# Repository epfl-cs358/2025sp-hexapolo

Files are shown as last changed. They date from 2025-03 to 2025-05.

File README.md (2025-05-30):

# 2025sp-hexapolo

## Table of Contents

- [Project Overview](#project-overview)
- [Features & Operation](#features-and-operation)
- [Hardware Requirements](#hardware-requirements)
- [Software Requirements](#software-requirements)
- [Installation](#installation)
- [Project Structure](#project-structure)
- [Acknowledgments](#Acknowledgments)
- [License](#license)

## Project Overview

The Hexapolo Bot is a six-legged robot that can find and follow a person by listening to their
voice and looking at them. It starts by saying “Marco” and waits for someone to reply “Polo.”
When it hears the reply, the robot uses four microphones to figure out which direction the sound
came from. Then, it turns to face that direction and checks with its camera if a person is there.
If it sees someone, it walks toward them and stops when it is about one meter away. After that,
the robot will follow the person as they move.

The project’s goal was to combine sound detection, camera vision, and motor control so the robot
can interact with people.

### Pictures

| Front View | Back View |
| --- | --- |
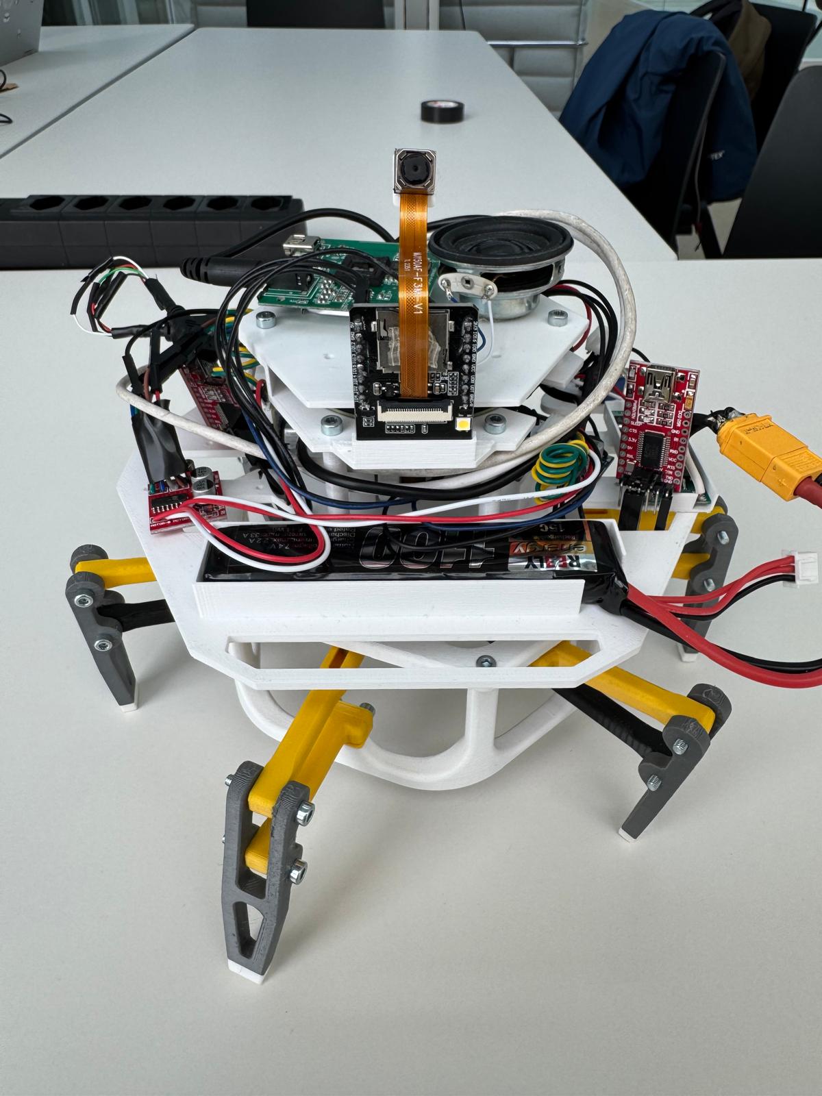
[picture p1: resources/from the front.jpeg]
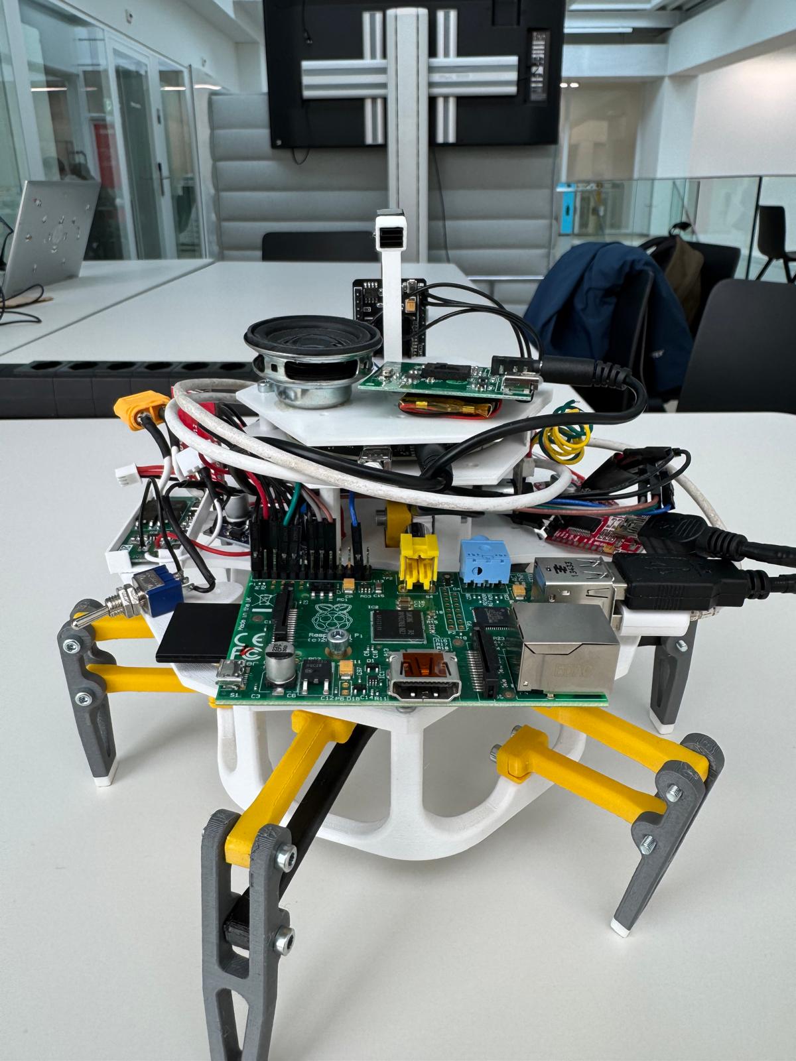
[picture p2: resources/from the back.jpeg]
|  |  |

| Below View | Inside View |
| --- | --- |
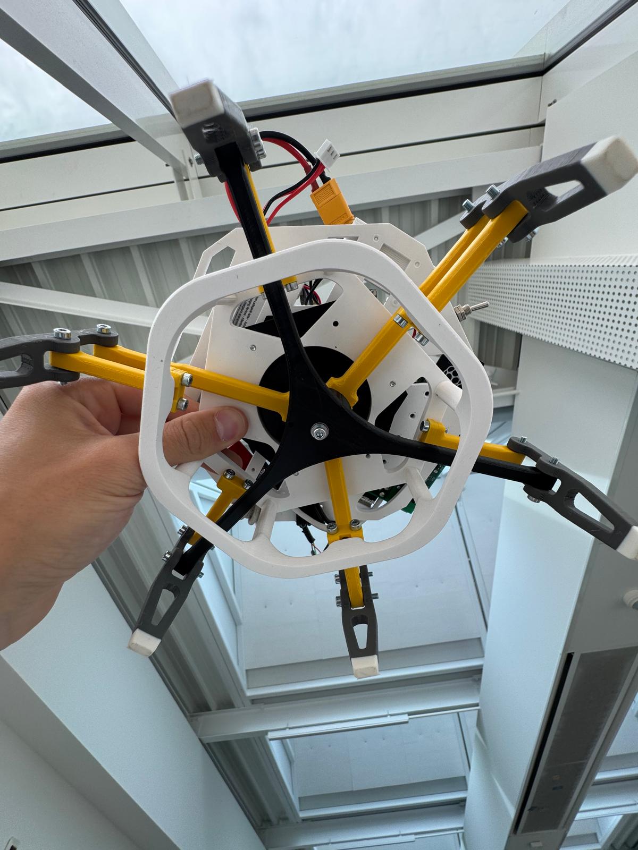
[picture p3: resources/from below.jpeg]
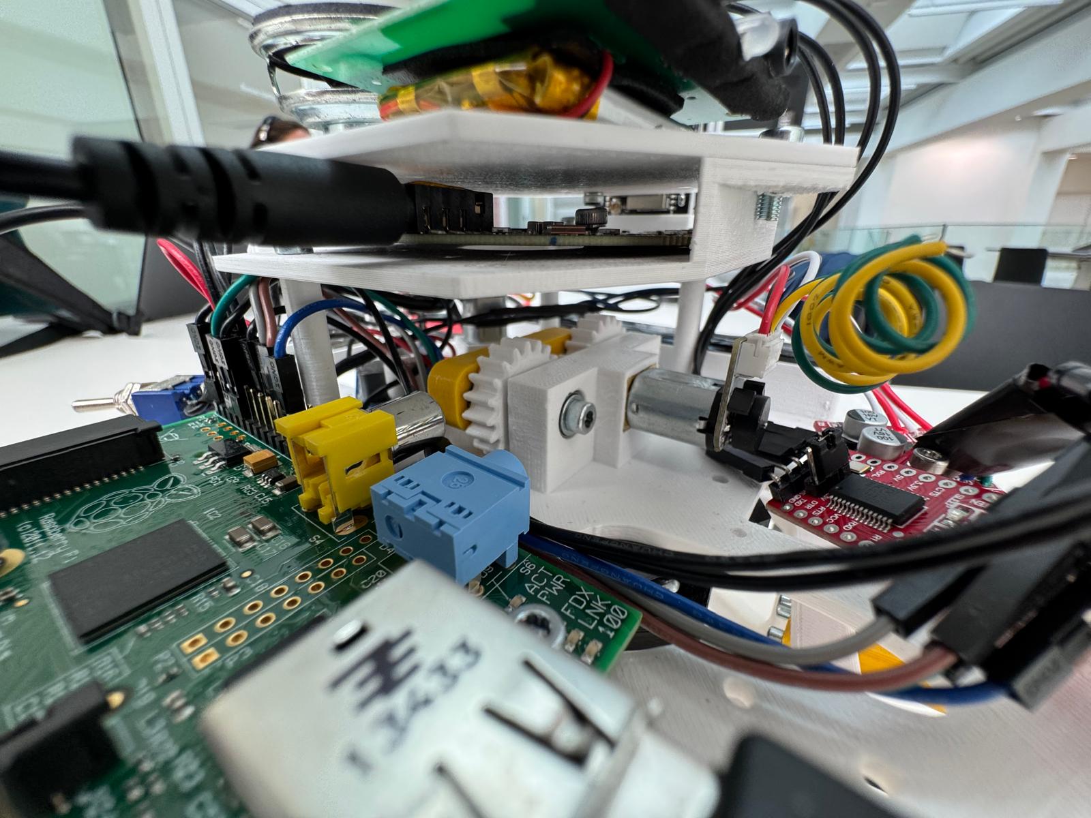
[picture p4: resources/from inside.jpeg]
|  |  |

| Live Video Feed from the Esp32Cam   |
| ----------------------------------- |
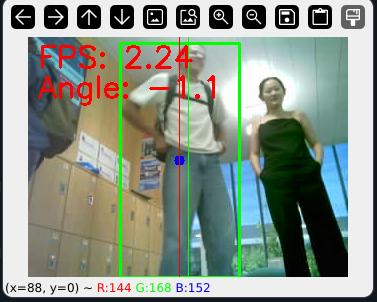
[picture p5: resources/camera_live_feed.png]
|  |

### Videos

Video clip of hexapolo having its first steps :

https://github.com/user-attachments/assets/a82f1c71-6dc9-49f4-babd-78dbcbe76842

Video clip of hexapolo tracking a person :

https://github.com/user-attachments/assets/ddf52e5b-f97f-4ff6-8985-b9ae90d72b5c

### Demo Video

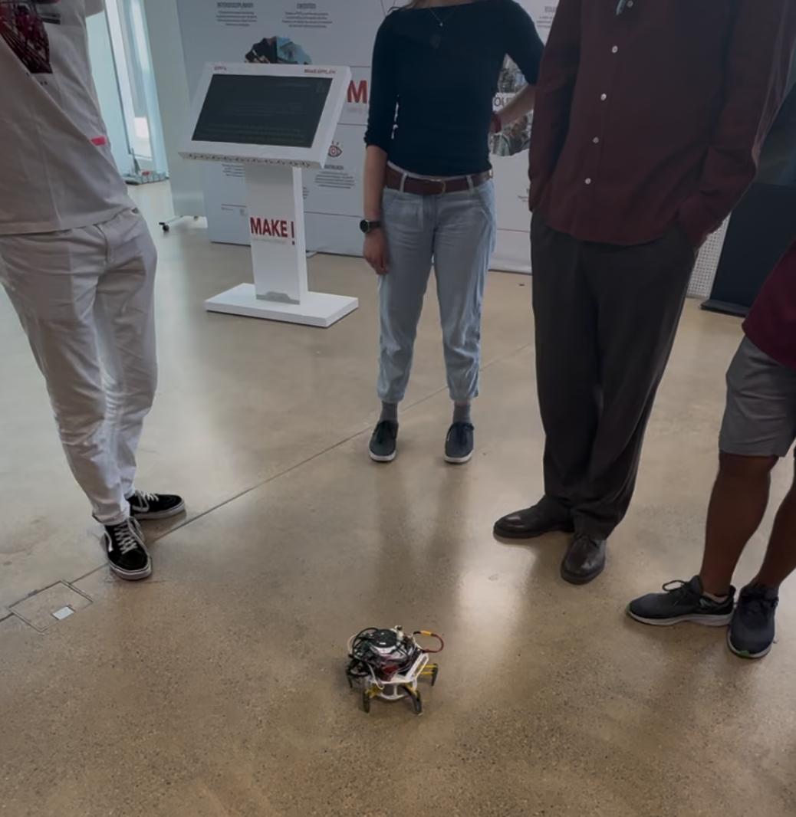
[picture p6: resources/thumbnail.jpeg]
Watch the video (https://youtube.com/shorts/G5ZAEMDvShg)


### Hardware overview

The Legs and mechanical links to control the legs :
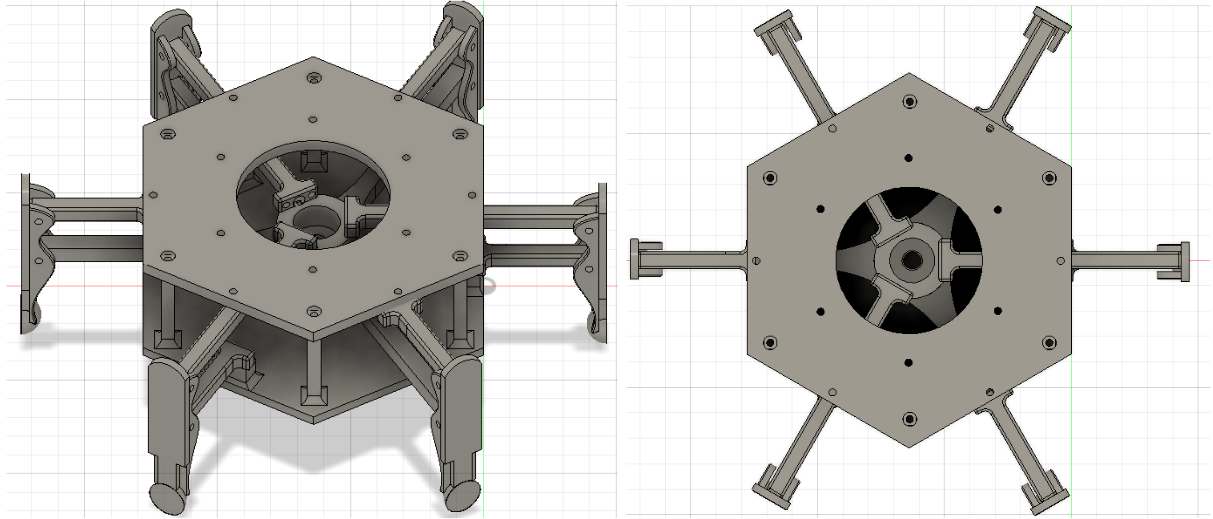
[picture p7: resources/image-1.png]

T-bar, gears and motors to rotate heads and control the movement of the legs :
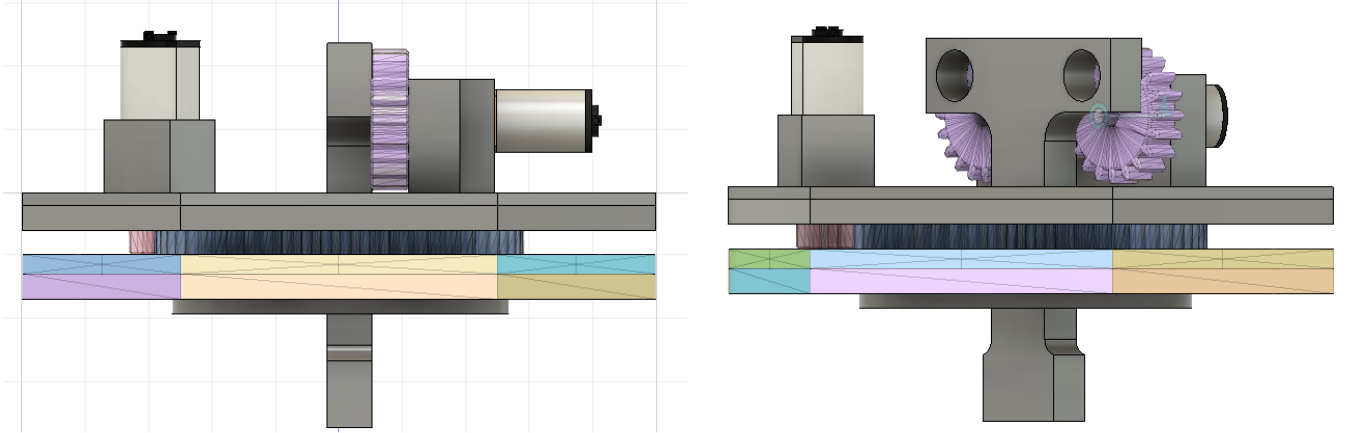
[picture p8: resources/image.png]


### Electrical Overview

Please note that the following diagram does not include the USB connections between the
FTDI board and the Raspberry Pi as well as that between the microphone array (also not
included) and the Raspberry Pi. Furthermore, note that the speaker amplifier will also be wired
to a 3.5mm headphone jack, which will plug into the microphone array, through its A+ and A-
ports.
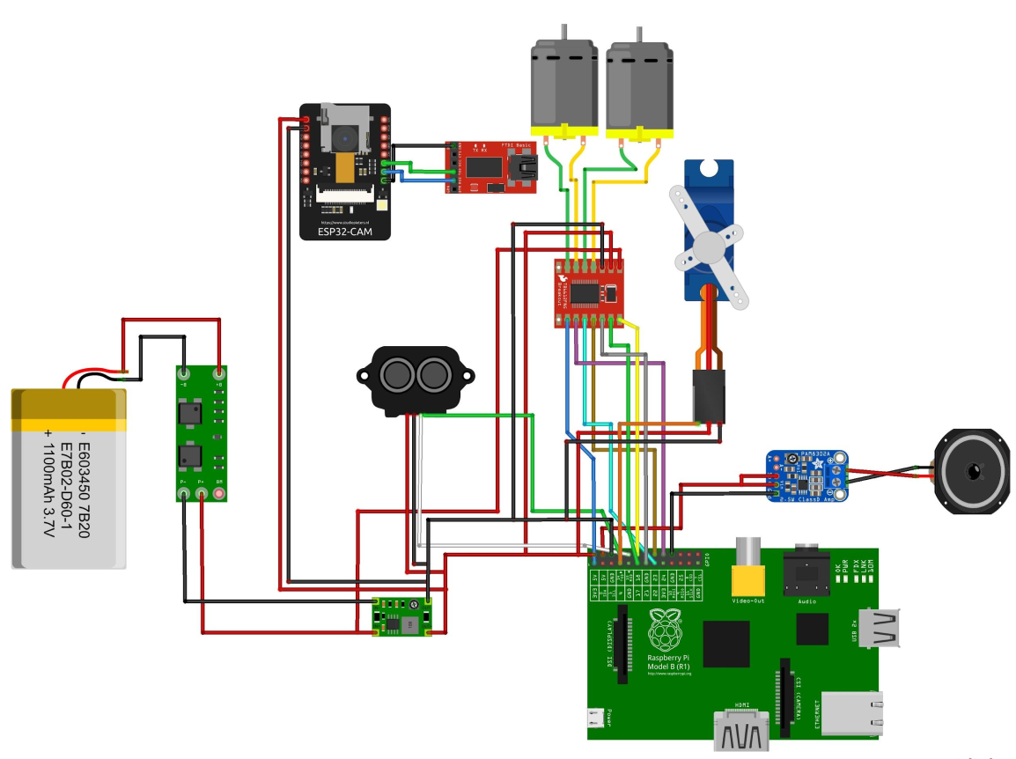
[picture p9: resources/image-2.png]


## Features and Operation

- **Keyword Detection:** The robot will listen for the word “Polo” and react when it hears it.
- **Sound Direction Estimation:** It will use four microphones and a time difference of arrival
  (TDoA) method to figure out which direction the sound came from.
- **Turning Toward the Sound:** After detecting the direction of the sound, the robot will rotate
  to face that direction.
- **Visual Detection:** The robot will use its camera to check if there is a person in front of it.
- **Walking Toward the Person:** The robot will move toward the person and stop when it is
  about 50 cm away.

The following is an overview of the decision tree outlining Hexapolo's main algorithm :



## Hardware Requirements

### Computer

- **Raspberry Pi 1**

  Note : none of our scripts were tested on any Raspberry Pi other than RPi1. However, because of good backward compatibility, all scripts tested on RPi1 should work on any next iteration of the board. Furthermore, you might encounter a few difficulties linked to the limited computing capabilities of the RP1. Using a more recent iteration of the Raspberry Pi, such as the RPi4, will make the reproducibility process significantly easier.

### Power Source

- **2S 7.4V LiPo battery** (e.g. 2S 7.4V lipo 1100mAh 15C with xt60 connector)
- **DC-DC buck converter** (e.g. WaveShare 6-36V to 5V/3.3V 4A DC-DC buck step down converter)

### Sensors

- **Mic Array** (e.g. ReSpeaker Mic Array v2.0)
- **esp32 Camera** (e.g. AI thinker esp 32-cam)
- **FTDI USB-to-serial** (e.g. FTDI FT232RL USB To TTL Serial Adapter Module)

### Sound Output & Speaker

- **Buzzer** (e.g. Purecrea Piezo buzzer active)
- **Speaker**

For our implementation, we stripped out both the speaker and the amplifier from an unbranded speaker. In the same way, you could use whatever speaker with a jack plug you want. Note that the whole build is quite heavy proportionally to the motors, choose your speaker carefully, the lighter the better. We chose this component to save weight, and you might find this approach useful as well.

### Actuators

- **2x 300rpm 6V n20 motor** (200rpm motors would also work)
- **1.2A DC Motor Driver** (e.g. DFRobot Fermion TB6612FNG 2x1.2A DC Motor Driver)
- **Battery Protection Board** (e.g. 8.4V 2S 20A Lithium Battery Protection BMS Protection Board)

### Mechanical Components

- **10x 8x4x3 Ball Bearing**

### Electrical Interfaces

- **Electrical Switch**
- **USB-A to Micro-USB cable**
- **USB-A to Mini-USB cable**

The combined weight of all the cables and wires might be too heavy for the motors to move effectively with the rest of the build. We suggest that you cut them short and solder the wires inside.

## Software Requirements

### OS

- **Linux (Debian)** running on the RPi1

### Dependencies

Due to the multiple features of our project, the use of computer vision and audio processing, a large, yet lightweight, set of dependencies need to be installed. They are all listed in the following file below :

- [Dependencies List](software/requirements.txt)

Among the list of software requirements, you'll find program that are crucial to make this project work. More specifically :

On Linux :

- **Minicom :** serial communication program used to run program in the Raspberry Pi from remote shell. This solution is heavily used and eliminates the need to connect additional peripherals to the RPi1 for control. [Minicom GitLab repository](https://salsa.debian.org/minicom-team/minicom)

On Windows :

- **PuTTY :** SSH and telnet client for Windows plateform. [PuTTY website](https://www.putty.org/)

## Installation

On the RPi1, download the libraries as a .tar.gz file :

```
pip download --no-binary :all: -r requirements.txt
```

Then, copy the downloaded libraries to a usb flash drive and transfer them to the RPi1.

On your laptop :

```
pip install -r requirements.txt
```

## Project Structure

The repository is organized as follows, important files have been highlighted:

    CAD/
    ├── Electrical Components                                     # 3D files for a few electrical components we use
    │   ├── ...
    │   └── ...
    ├── Electronic plate
    ├── Internal Mechanics                                        # 3D files for each mechanical piece of the gearbox
    │   └── ...
    ├── Moving Parts                                              # 3D files for each piece of the body
    │   └── ...
    └── New head with larger base plate                           # 3D files for each piece of the head
        └── ...
    docs/
    software/
    ├── control                                                   # Basic scripts to control hexapolo
    │   └── __pycache__
    ├── esp                                                       # Scripts handling the communication between the laptop and hexapolo
    ├── laptop                                                    # Scripts processing the video feed from the esp32 cam and communicating with it via Wifi
    ├── machine_learning                                          # Scripts used to train the ML model
    └── pi                                                        # Scripts running on the RPi 1
        ├── model
        │   ├── ...
        │   └── ...
        └── usb_4_mic_array                                       # Scripts related to audio processing with the mic array
            ├── single_frequency_sound_recognizance               # Scripts to recognize a single frequency sound in the case where the voice recognition model couldn't work
            └── test                                              # Unit tests

## Acknowledgments

We drew inspiration for Pilotgeek's project ([YouTube video](https://www.youtube.com/watch?v=cc_Njp_cz18)) that demonstrated a similar concept of a six-legged robot. His work provided valuable insights and helped us build Hexapolo.

## License

This project is licensed under the MIT License.

You are free to use, modify, and distribute this software, provided that proper attribution is given to the original authors. For more details, please refer to the LICENSE file included in this repository.

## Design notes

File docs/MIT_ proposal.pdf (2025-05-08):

Making Intelligent Things: HexaPolo Bot

# HexaPolo Bot: Revised Team Project Proposal

Zakaria Laribi, Nagyung Kim, Roméo Maignal, Tuan Dang Nguyen

## 1. Introduction

Robots that can sense and react to their surroundings are becoming more common, and combining different types of sensors can make these robots smarter and more interactive. This project explores how a walking robot can use sound and vision together to find and follow a person. The idea is inspired by the classic game Marco Polo, where one player has to find another by listening to their voice.

Instead of relying only on one sensor, the Hexapolo Bot uses microphones, a camera, and a lidar scanner to understand its environment. This project is a way to experiment with how different technologies—such as sound direction detection and computer vision—can be used to build a robot that moves and reacts to people in real time. The focus is not only on making the robot move but also on making it respond to human interaction in a playful and intelligent way.

## 2. Extended Project Description

### 2.1. Project Overview

The Hexapolo Bot is a six-legged robot that can find and follow a person by listening to their voice and looking at them. It starts by saying “Marco” and waits for someone to reply “Polo.” When it hears the reply, the robot uses four microphones to figure out which direction the sound came from. Then, it turns to face that direction and checks with its camera if a person is there. If it sees someone, it walks toward them and stops when it is about one meter away. After that, the robot will follow the person as they move.

The project’s goal is to combine sound detection, camera vision, and motor control so the robot can interact with people. The robot will also have optional features, like working in a noisy room or avoiding obstacles using a lidar scanner. The work is divided into small steps to make sure each part works well before moving to the next.

### 2.2. Functional Specifications

The Hexapolo Bot will be able to do several things to find and follow a person.

These are the main features it needs to have:

- Keyword Detection: The robot will listen for the word “Polo” and react when it hears it.
- Sound Direction Estimation: It will use four microphones and a time difference of arrival (TDoA) method to figure out which direction the sound came from.
- Turning Toward the Sound: After detecting the direction of the sound, the robot will rotate to face that direction.

- Visual Detection: The robot will use its camera to check if there is a person in front of it.
- Short Verbal Response: Once the robot detects a person, it will say a short phrase to confirm it.
- Walking Toward the Person: The robot will move toward the person and stop when it is about one meter away.
- Following the Person: After reaching the person, the robot will follow them as they move around.

Optional Features:

- Noise Handling: The robot will be able to detect the “Polo” keyword even in a noisy room.
- Obstacle Avoidance: The robot will use a lidar scanner to detect obstacles and avoid them while moving.

Here is a decision tree illustrating the functional specifications :

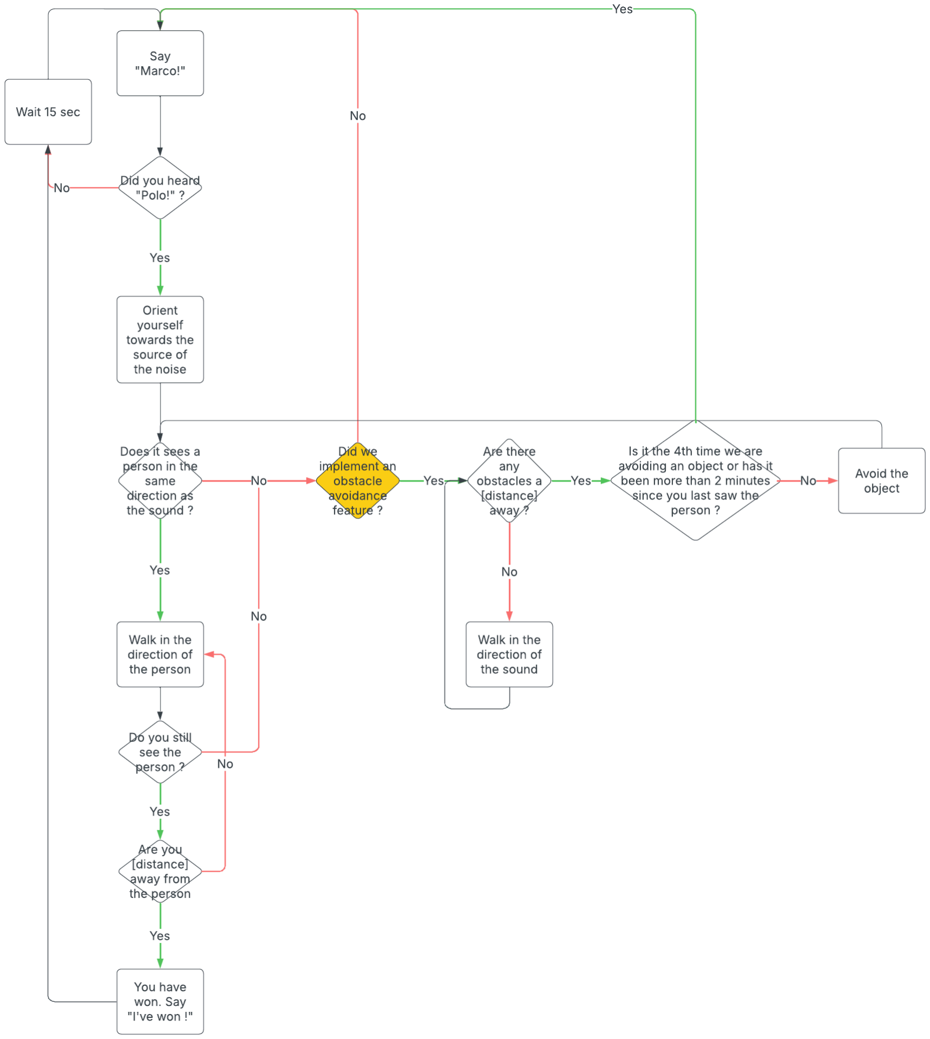
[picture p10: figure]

### 2.3. Technical Approach

The robot’s system uses a combination of microphones, a camera, sensors, and motors, all connected to a Raspberry Pi and ESP32-CAM, as shown in the wiring diagram below.

The robot’s main task is to find and follow a person based on sound and visual information. For this, the following hardware and techniques will be used:

- Sound Direction Detection:
The robot uses a ReSpeaker Mic Array (4-microphone setup) connected to a Raspberry Pi. When someone says “Polo,” the robot compares the tiny time differences of when the sound reaches each microphone. This method is called TDoA (Time Difference of Arrival). It helps the robot calculate which direction the sound is coming from. For sound recognition and direction detection, the project will use the open-source library provided by Seeed Studio: https://github.com/respeaker/mic_array
- Person Detection and Tracking:
The robot uses an ESP32-CAM module with an external antenna to capture video and check if a person is in front. The camera sends the images to the Raspberry Pi for processing. The robot does not need to recognize specific people; it only checks if any person is there.
- Motor and Movement Control:
The robot uses two N20 DC motors to drive its movement and a TB6612FNG motor driver to control the motors safely. It also uses a SG90 servo motor to adjust the camera or other parts if needed.
- Distance-Based Following with TFMini LiDAR
To maintain a consistent following distance of about 1 meter, the robot uses a TFMini LiDAR sensor. It helps the robot follow the person smoothly by constantly checking how far ahead the person is. (This is considering the setup that there are no multiple people close to each other)
- Sound Feedback:
The robot responds with a short phrase using an Adafruit Mini Metal Speaker and a small PAM8302 audio amplifier to make sure the sound is loud enough.
- Power Supply:
The robot is powered by a 2S 7.4V LiPo battery and uses a DC-DC buck converter to safely supply power to the components.

### 2.4. Milestones

To build the Hexapolo Bot step by step, the work is divided into smaller goals, called milestones. Each milestone focuses on one part of the robot’s behavior.

Milestone 1 – Sound Detection & Turning
In a quiet room without obstacles, the robot listens for the word “Polo.” It uses the microphone array and a keyword detection system to recognize the word. Then, it uses the TDoA method to find the direction of the sound. After that, the robot turns toward the sound and uses its camera to look for a person.

Milestone 2 – Walking to the Person
Once the robot detects a person, it moves toward them using its motors. It stops when it is about one meter away. Distance is checked using either the ultrasonic sensor or LiDAR.

Milestone 3 – Following the Person
The robot keeps following the person as they move around. It uses the lidar to keep track of the person’s location and updates its movement.

Milestone 4 (Optional) – Working in Noisy Rooms
The robot will be tested in a noisy environment. It will use sound-processing libraries from the ReSpeaker project to help it detect the “Polo” keyword even when there is background noise.

Milestone 5 (Optional) – Obstacle Avoidance
The robot will use a TFmini Plus LiDAR scanner to detect obstacles while moving. If something is in its path, it will stop and change direction to avoid collisions.

## 3. Complete Technical Drawings

### 3.1. CAD Drawings

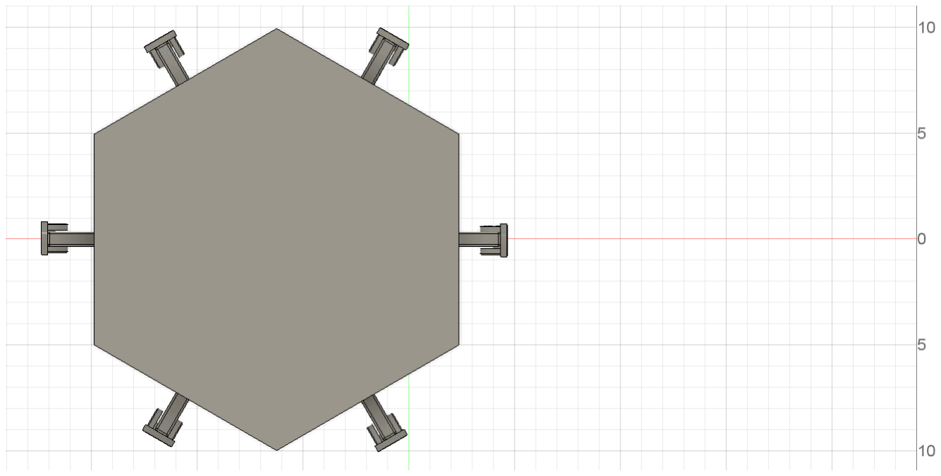
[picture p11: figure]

Figure 1: The prototype looking from above (the numbers on the vertical axis are in cm)

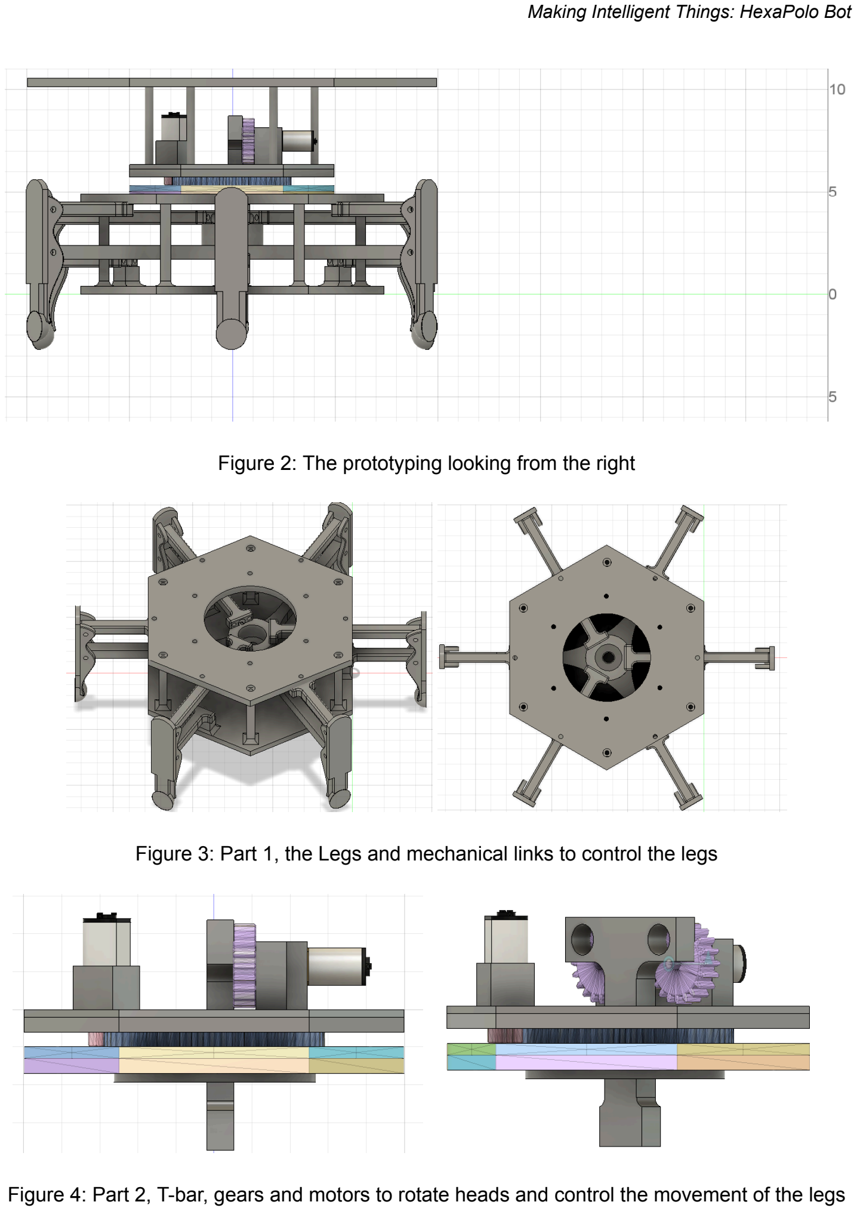
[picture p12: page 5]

Figure 2: The prototyping looking from the right

Figure 3: Part 1, the Legs and mechanical links to control the legs

Figure 4: Part 2, T-bar, gears and motors to rotate heads and control the movement of the legs

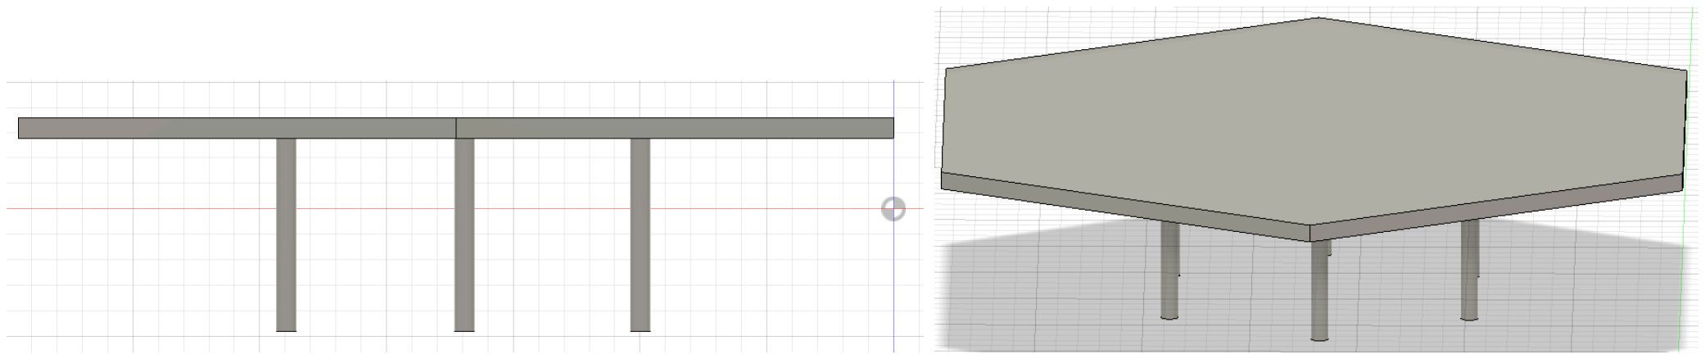
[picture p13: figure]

Figure 5: Part 3, the platform that holds all the electronics

### 3.2. Electrical or Circuit Schematics

Please note that the following diagram does not include the USB connections between the FTDI board and the Raspberry Pi as well as that between the microphone array (also not included) and the Raspberry Pi. Furthermore, note that the speaker amplifier will also be wired to a 3.5mm headphone jack, which will plug into the microphone array, through its A+ and Aports.

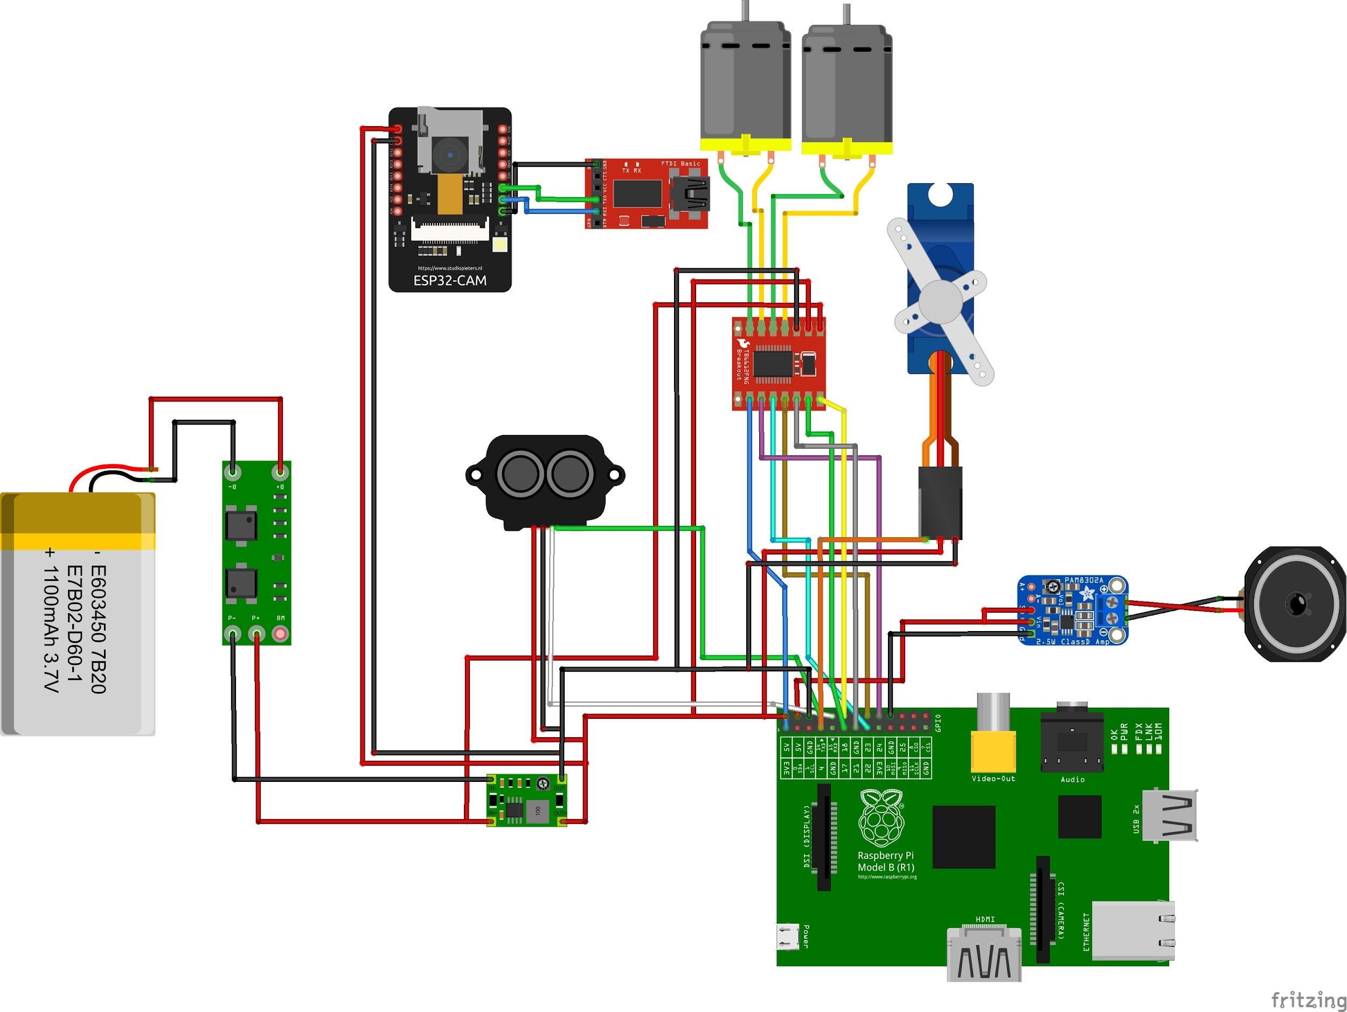
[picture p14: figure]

## 4. Bill of Materials (BOM)

- AI thinker esp32-cam with antenna - 13. - cs358 stock
- FTDI USB-to-serial - 2. - cs358 stock
- sg90 micro servo - 3. - cs358 stock
- raspberry pi 1 B - in stock
- Adafruit Mini Metal Speaker - 8.9 -https://www.digitec.ch/en/s1/product/adafruit-mini-metal-speaker-loudspeaker-electronic s-modules-5998730 (https://www.digitec.ch/en/s1/product/adafruit-mini-metal-speaker-loudspeaker-electronics-modules-5998730)

- DFRobot Fermion TB6612FNG 2x1.2A DC Motor Driver - 14.9 -https://www.digitec.ch/en/s1/product/dfrobot-fermion-tb6612fng-2x12a-dc-motor-driver-d evelopment-boards-kits-24935800 (https://www.digitec.ch/en/s1/product/dfrobot-fermion-tb6612fng-2x12a-dc-motor-driver-development-boards-kits-24935800)
- Tfmini Plus Lidar - 89 -https://www.fruugoschweiz.com/tfmini-plus-lidar-reichweitensensormodul-12-m-reichweite-hohe-bildrate-kleiner-blindbereich-hohe-genauigkeit/p-213832614-455740347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 (https://www.fruugoschweiz.com/tfmini-plus-lidar-reichweitensensormodul-12-m-reichweite-hohe-bildrate-kleiner-blindbereich-hohe-genauigkeit/p-213832614-4557403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)
- 300rpm 6V n20 motor - in stock
- 200rpm 6V n20 motor - in stock
- 2S 7.4V lipo 1100mAh 15C (with xt60 connector) - 12.95 -https://www.conrad.ch/fr/p/reely-pack-de-batterie-lipo-7-4-v-1100-mah-nombre-de-cellul es-2-15-c-softcase-xt60-2582340.html (https://www.conrad.ch/fr/p/reely-pack-de-batterie-lipo-7-4-v-1100-mah-nombre-de-cellules-2-15-c-softcase-xt60-2582340.html)
- WaveShare 6-36V to 5V/3.3V 4A DC-DC buck step down converter - 10.9 -https://www.digitec.ch/en/s1/product/waveshare-6-36v-to-5v33v-4a-dc-dc-buck-step-do wn-converter-development-boards-kits-53542221 (https://www.digitec.ch/en/s1/product/waveshare-6-36v-to-5v33v-4a-dc-dc-buck-step-down-converter-development-boards-kits-53542221)
- OV5640 camera - 9.95 -
https://www.fruugoschweiz.com/ov5640-module-de-camera-pour-carte-logicielle-esp32-cam-5-millions-de-pixels-c/p-331210929-730594189 (https://www.fruugoschweiz.com/ov5640-module-de-camera-pour-carte-logicielle-esp32-cam-5-millions-de-pixels-c/p-331210929-730594189)
- Goobay Jack plug 3.5 mm mono - 2.7 -https://www.digitec.ch/en/s1/product/goobay-jack-plug-35-mm-mono-audio-connectors-20604603 (https://www.digitec.ch/en/s1/product/goobay-jack-plug-35-mm-mono-audio-connectors-20604603)
- Purecrea Piezo buzzer active - 5.9 -https://www.digitec.ch/en/s1/product/purecrea-piezo-buzzer-active-development-boardskits-38633745 (https://www.digitec.ch/en/s1/product/purecrea-piezo-buzzer-active-development-boards-kits-38633745)
- ReSpeaker Mic Array v2.0 - 58.51 -https://www.reichelt.com/ch/en/shop/product/respeaker_mic_array_v2_0-248721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 (https://www.reichelt.com/ch/en/shop/product/respeaker_mic_array_v2_0-248721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)
- PAM8302 2.5W single channel Class D Audio power amplifier - 7.95 -https://www.fruugoschweiz.com/pam8302a-cjmcu-832-pam8302-25-w-einkanal-class-daudio-leistungsverstarkermodul-entwicklungsplatine/p-263124514-578035388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 (https://www.fruugoschweiz.com/pam8302a-cjmcu-832-pam8302-25-w-einkanal-class-d-audio-leistungsverstarkermodul-entwicklungsplatine/p-263124514-578035388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)

Total cost: 239.66

## 5. Work Breakdown Structure

### 5.1. Task Breakdown

The chart below outlines our planned task breakdown for the project. While it gives a clear structure for how we aim to progress week by week, we are approaching the plan with flexibility and will adapt it as needed based on testing outcomes and unexpected challenges.

The tasks marked as optional represent features we would like to implement if time allows, but they will only be pursued after all core features are completed and working reliably.

The timeline for the core features is intentionally planned with more buffer time to handle possible errors and unexpected issues, while the optional features are scheduled more tightly so that, if we finish the core tasks earlier than expected, we can immediately move forward without losing time.

Week | Task | Dependencies / Note

Week 7: Assemble 3D-printed body, set up camera, motor, and Raspberry Pi environment

7.1 | Print and assemble 3D printed robot body | Independent
7.2 | Set up ESP32-CAM and FTDI programmer, test video stream | In-stock components
7.3 | Research and implement basic person detection (presence only) using ESP32-CAM | In-stock components
7.4 | Set up Raspberry Pi environment (GPIO, Python, libraries) | In-stock components

Week 8: Assemble full electronics, integrate mic array, build first moving robot

8.1 | Receive, test and integrate mic array hardware | Needs delivery
8.2 | Assemble motor driver and one N20 motor, test basic forward/backward movement | Need delivery
8.3 | Test and finalize keyword detection (“Polo”) using mic array
8.4 | Assemble electronics: connect motors, sensors, power system | Needs motor driver, battery
8.5 | Assemble the initial robot | This is the very first moving robot we will have

Week 9 (Milestone 1): Implement sound direction detection & turning behavior for person detection

9.1 | Implement TDoA sound direction detection | Needs working mic array
9.2 | Integrate sound direction detection with motor turning behavior | Needs sound direction + motor setup
9.3 | Integrate person detection with turning behavior | Needs vision + turning working
9.4 | Test: turn + detect in quiet room | First prototype (Milestone 1)

Week 10 (Milestone 2): Add walking-to-person behavior and test approach in quiet room

10.1 | Fix bugs or unstable behavior after prototype test | System improvement
10.2 | Implement walking-to-person behavior and stop at 1m distance | Needs motor + person detection
10.3 | Test: turn + detect + walk-to-person behavior in quiet | Second prototype

room | (Milestone 2)

Week 11 (Milestone 3, full prototype): Implement following the human behavior and complete core Hexapolo Bot features

11.1 | Connect TFmini lidar module to Raspberry Pi
11.2 | Integrate lidar distance data into Raspberry Pi control loop
11.3 | Implement the following person behavior (continuous person tracking) | Builds on turn-detect-walk behavior
11.4 | Test: turn + detect + walk-to-person behavior + follow the person in quiet room | The full Hexapolo bot prototype with all of the essential features (Milestone 3)

Week 12 (Milestone 4): (Optional) Add noise filtering feature and connect lidar module for obstacle avoidance while approaching visible person

12.1 | [Optional] Integrate selected noise filtering method into existing keyword detection pipeline | Needs working keyword detection
12.2 | [Optional] Test: keyword detection performance in simulated noisy environment | Test until which level of noise it can handle, and document it (Milestone 4)
12.3 | [Optional] Design basic obstacle avoidance behavior with lidar (stop & turn when obstacle detected)
12.4 | [Optional] Implement obstacle avoidance while walking toward visible person
12.5 | [Optional] Test: obstacle avoidance in clean room while approaching visible person

Week 13 (Milestone 5): (Optional) Implement search behavior when person is not visible

13.1 | [Optional] Research and choose a method for searching the person when not visible (strategy decision in addition to what we already have, ex. Saying Marco again after 4 trial)
13.2 | [Optional] Integrate search behavior with obstacle avoidance | Requires both search logic + avoidance working
13.3 | [Optional] Test full system: obstacle avoidance + search behavior | Final integrated test (Milestone 5)

### 5.2. Gantt Chart

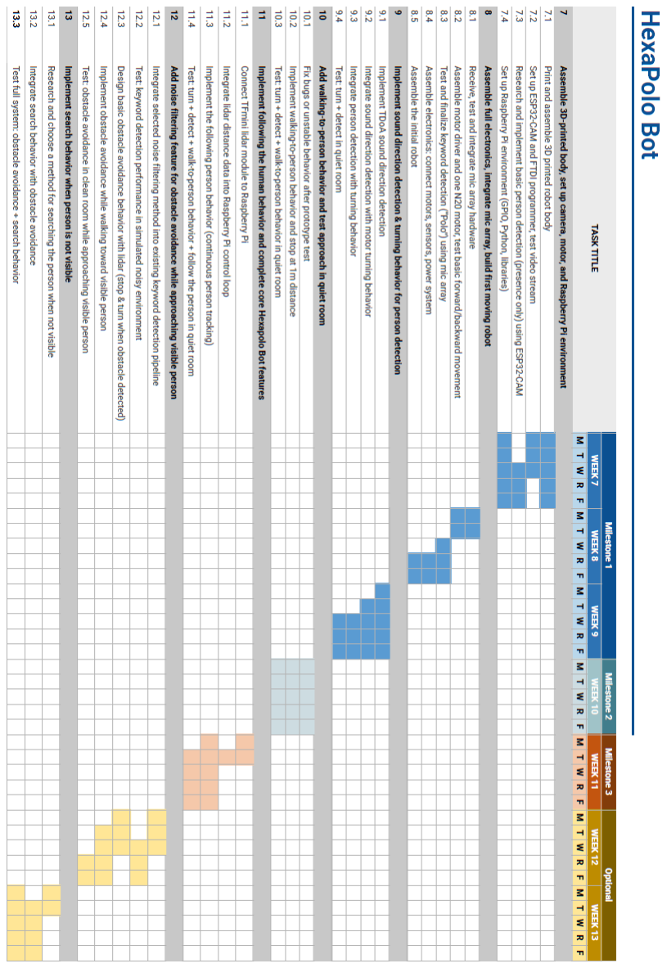
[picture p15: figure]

https://docs.google.com/spreadsheets/d/1xnIqV8nKbMYVABpta7GscwPPvCl3ueHyudp6yGAwllQ/edit?usp=sharing

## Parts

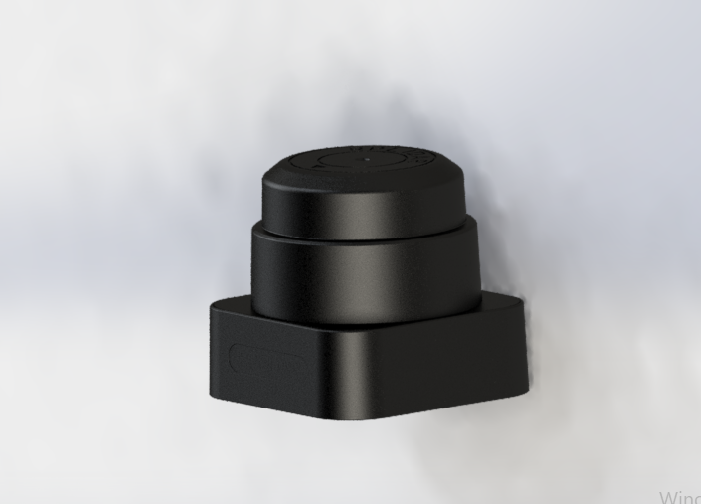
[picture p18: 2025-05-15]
CAD/Electrical Components/rplidar-s1-360-laser-scanner-1.snapshot.2/Ekran görüntüsü 2022-02-06 154033.png

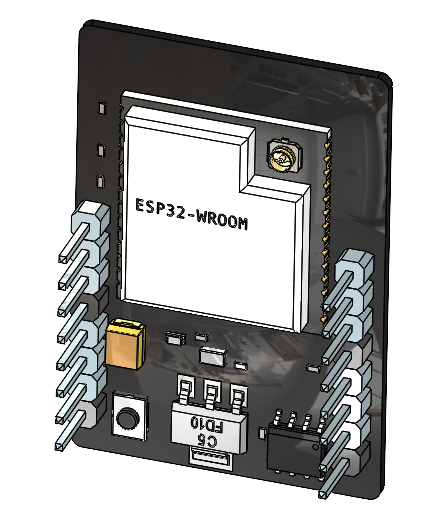
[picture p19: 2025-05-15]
CAD/Electrical Components/esp32-cam-wifi-bluetooth-1.snapshot.5/ESP32 CAM 3.PNG

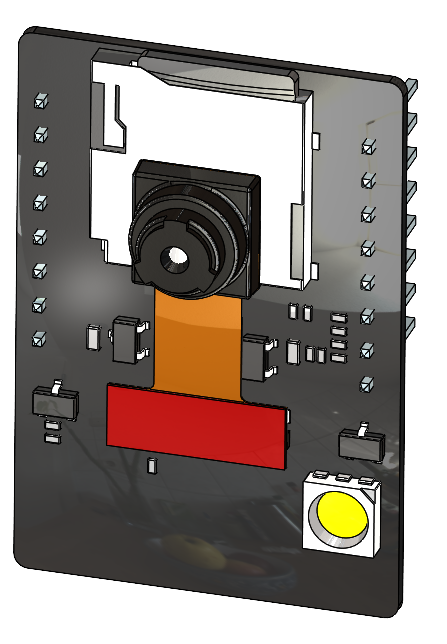
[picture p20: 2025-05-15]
CAD/Electrical Components/esp32-cam-wifi-bluetooth-1.snapshot.5/ESP32 CAM.PNG

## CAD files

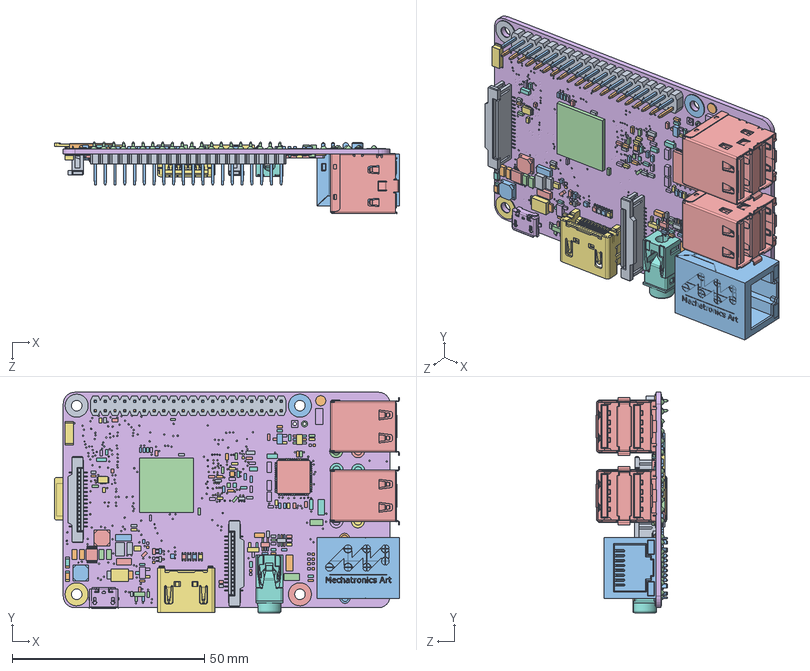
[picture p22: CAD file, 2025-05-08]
CAD/Electrical Components/Solidworks Complete Assembly/Raspberry Pi 3.SLDASM
89.6 x 57.3 x 18.6 mm
Raspberry Pi 3157
Raspberry Pi 3242 x 20
Raspberry Pi 3266 x 20
raspberry_pi_3(bar_180_2x20)
MOLEX_672983090 x 2
molex_0473460001
molex_0471510001
PJ-322
te_1-1734248-5 x 2
MOLEX_1040310811
raspberry_pi_B_(RJ45)
Raspberry Pi 312
Raspberry Pi 314
Raspberry Pi 3172
Raspberry Pi 3173
Raspberry Pi 3174
Raspberry Pi 3175
Raspberry Pi 3176
Raspberry Pi 3177
Raspberry Pi 3178
Raspberry Pi 3179
Raspberry Pi 3180
Raspberry Pi 3181
Raspberry Pi 3182
Raspberry Pi 3183
Raspberry Pi 3184
Raspberry Pi 3185
Raspberry Pi 3186
Raspberry Pi 3187
Raspberry Pi 3188
Raspberry Pi 3189
Raspberry Pi 3190
Raspberry Pi 3191
Raspberry Pi 3192
Raspberry Pi 3193
Raspberry Pi 3194
Raspberry Pi 3195
Raspberry Pi 3196
Raspberry Pi 3197
Raspberry Pi 3198
Raspberry Pi 3199
Raspberry Pi 3200
Raspberry Pi 3201
Raspberry Pi 3202
Raspberry Pi 3203
Raspberry Pi 3204
Raspberry Pi 3205
Raspberry Pi 3206
Raspberry Pi 3207
Raspberry Pi 3208
Raspberry Pi 3209
Raspberry Pi 3210
Raspberry Pi 3211
Raspberry Pi 3212
Raspberry Pi 3213
Raspberry Pi 3214
Raspberry Pi 3215
Raspberry Pi 3216
Raspberry Pi 3217
Raspberry Pi 3218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

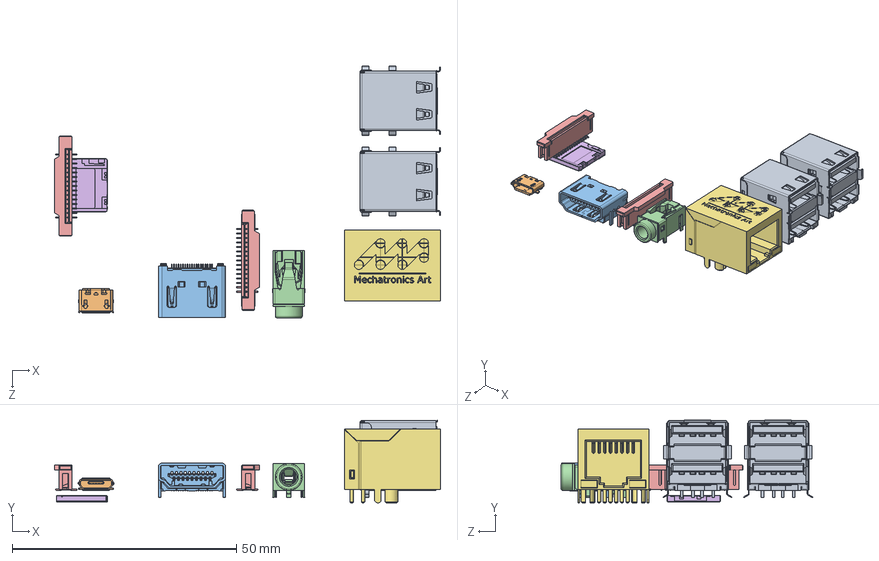
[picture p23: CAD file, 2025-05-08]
CAD/Electrical Components/Solidworks Complete Assembly/Rpi components/RPi3_ModelB v1.sldasm
86.1 x 18.5 x 56.1 mm
MOLEX_672983090 x 2
molex_0473460001
molex_0471510001
PJ-322
te_1-1734248-5 x 2
MOLEX_1040310811
raspberry_pi_B_(RJ45)

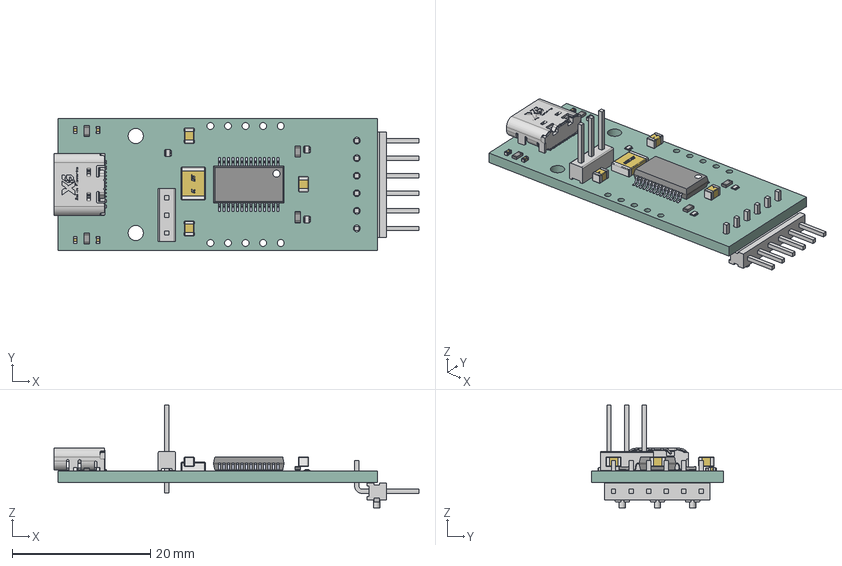
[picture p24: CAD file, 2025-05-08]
CAD/Electrical Components/ftdi-uart-ft232-usb-c-type-1.snapshot.3/FTDI UART FT232 USB board v7.step
52.8 x 19.1 x 14.9 mm
FT232RL
xb-u50137r16ga042
Base_22 x 3
Termination_22 x 6
Base_121
Termination_121 x 2

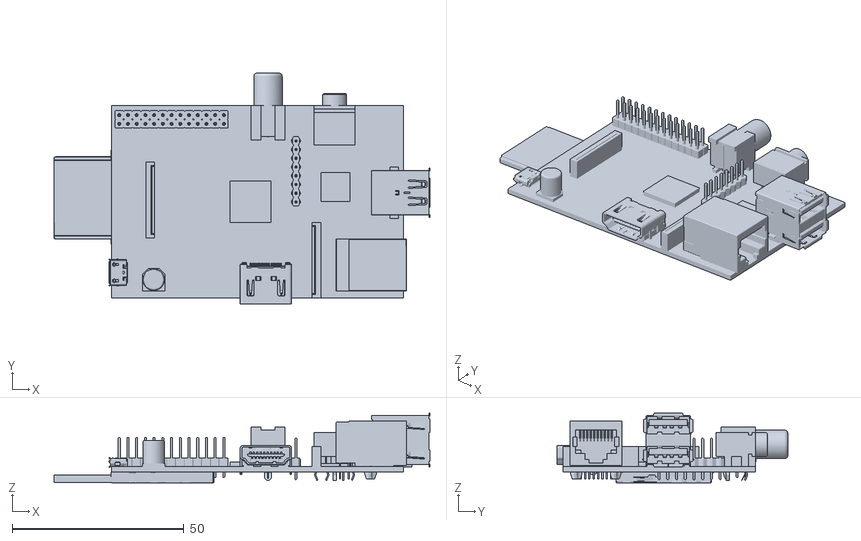
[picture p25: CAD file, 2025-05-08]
CAD/Electrical Components/raspberry-pi-model-b.snapshot.9/Renderings/raspberrypi_b.stl
109.5 x 67.3 x 20.3

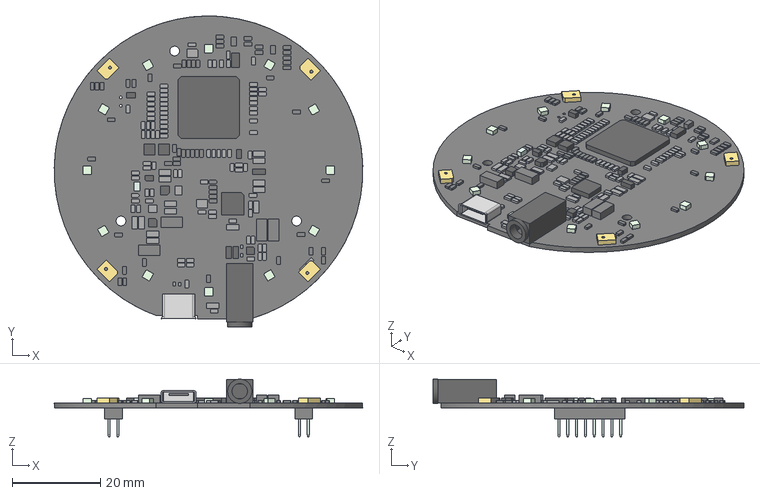
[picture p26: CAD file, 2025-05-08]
CAD/Electrical Components/RESPEAKER MIC-3D v2.0.stp
70.0 x 70.6 x 13.1 mm

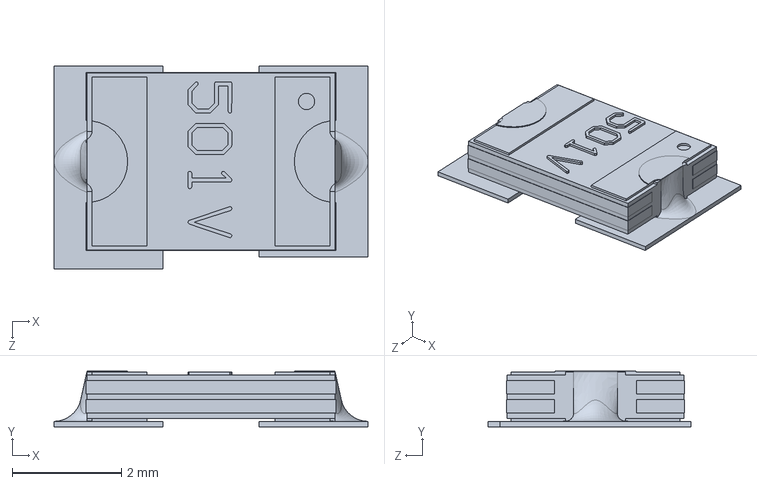
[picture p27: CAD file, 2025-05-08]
CAD/Electrical Components/Solidworks Complete Assembly/Rpi components/mf-msmf050-2.SLDPRT
5.75 x 1.02 x 3.72 mm

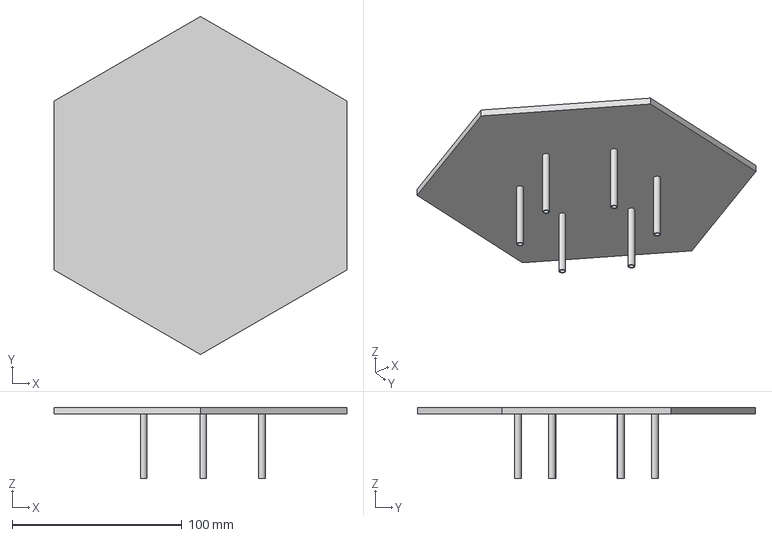
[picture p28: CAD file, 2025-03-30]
CAD/Electronic plate/Electronic plate.step
172.6 x 199.3 x 42.0 mm

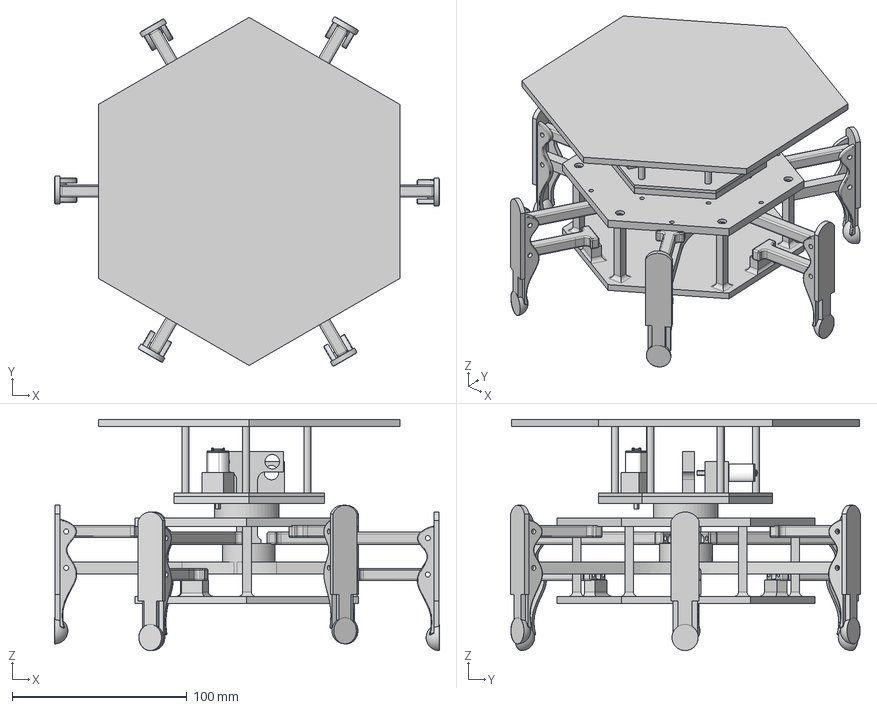
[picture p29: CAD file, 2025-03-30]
CAD/Hexapod global 3D structure.step
220.4 x 200.3 x 132.3 mm
Lower Cage
Control link x 6
Lower Cage Lid
Side Link x 3
Tri Link
Leg x 6
B - gear box
Upper collar
Upper collar_1
Wobbly wobb
Brazo M
1x_Drive_Pinion
2x_Spur_Gear x 2
1x_Rotation_Pinion
Brazo M_1
Upper collar_2
Lower collar
Electronic plate

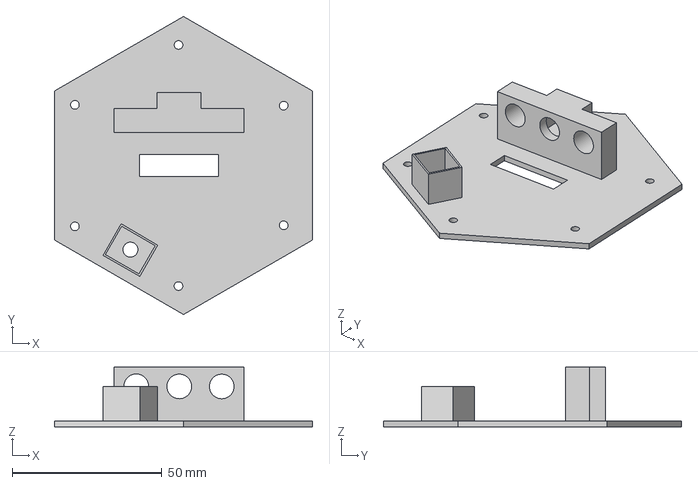
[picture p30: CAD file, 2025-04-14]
CAD/Internal Mechanics/3D parts/Gear box.step
86.3 x 99.6 x 20.0 mm

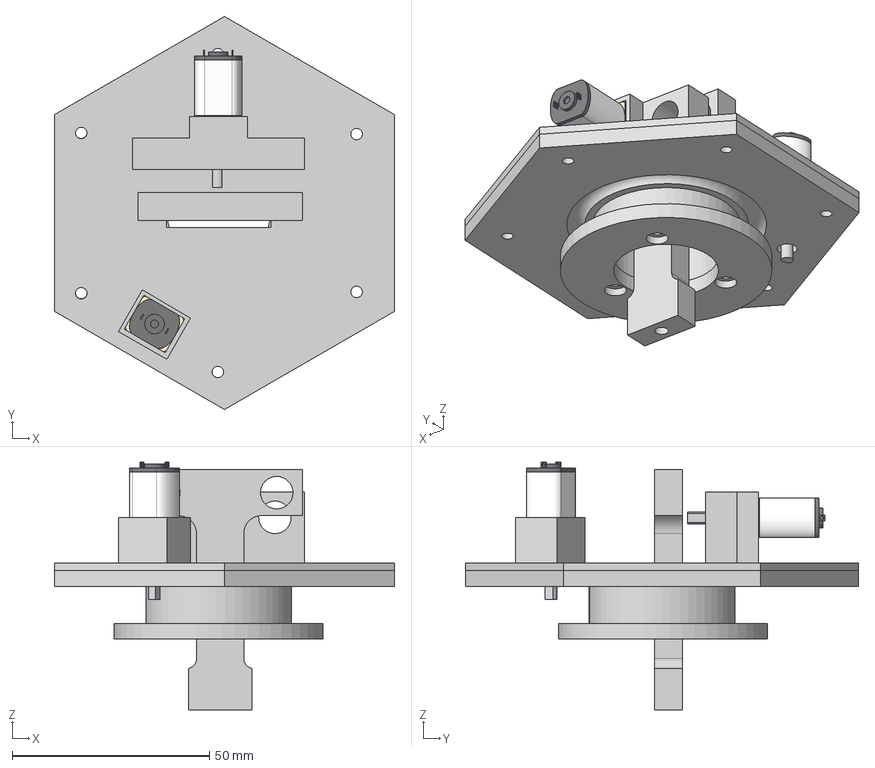
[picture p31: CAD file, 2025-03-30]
CAD/Internal Mechanics/Combined internal mechanics.step
86.3 x 99.6 x 62.8 mm
B - gear box
Upper collar
Upper collar_1
Wobbly wobb
Brazo M
1x_Drive_Pinion
2x_Spur_Gear x 2
1x_Rotation_Pinion
Brazo M_1
Upper collar_2
Lower collar

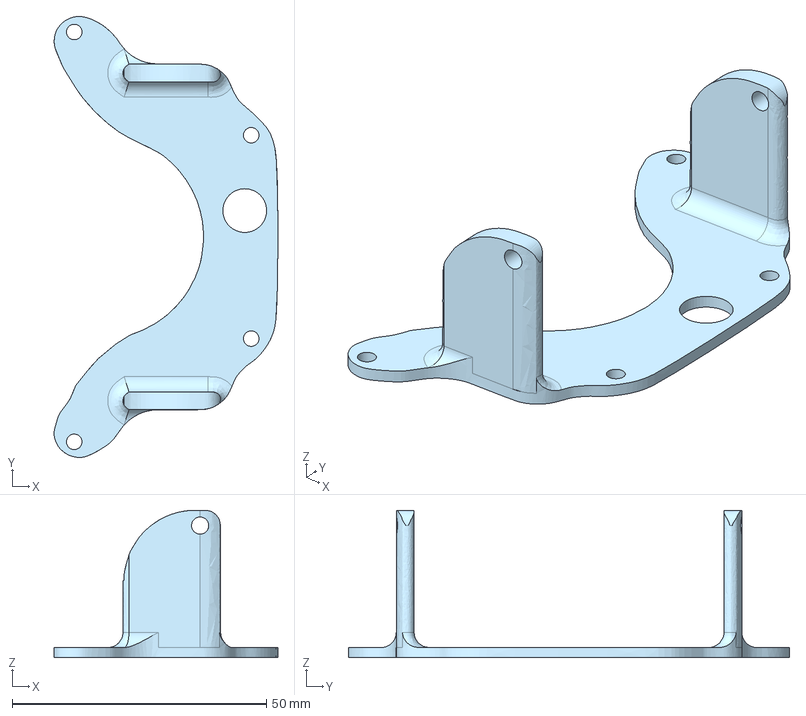
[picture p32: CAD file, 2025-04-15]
CAD/Moving Parts/3D parts/Head_Mount.step
44.0 x 86.8 x 29.0 mm

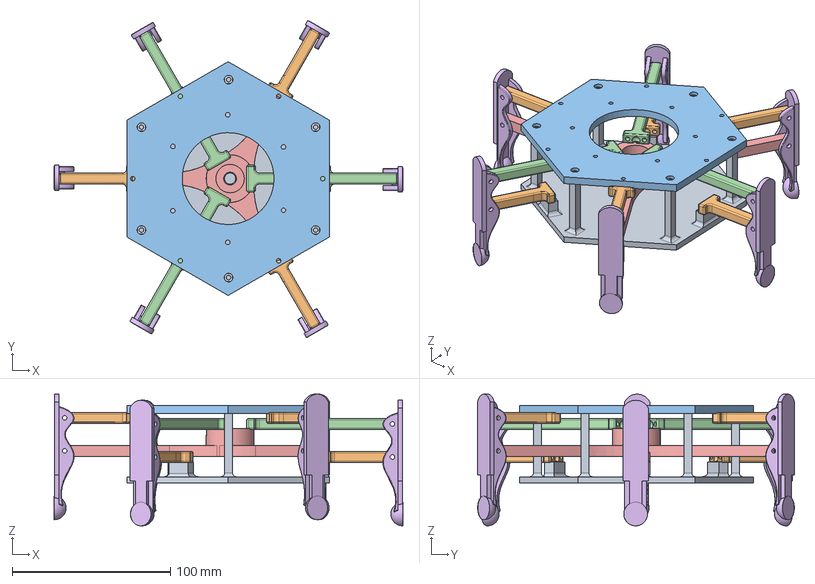
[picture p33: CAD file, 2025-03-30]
CAD/Moving Parts/All legs components.step
220.4 x 200.3 x 83.2 mm
Lower Cage
Control link x 6
Lower Cage Lid
Side Link x 3
Tri Link
Leg x 6

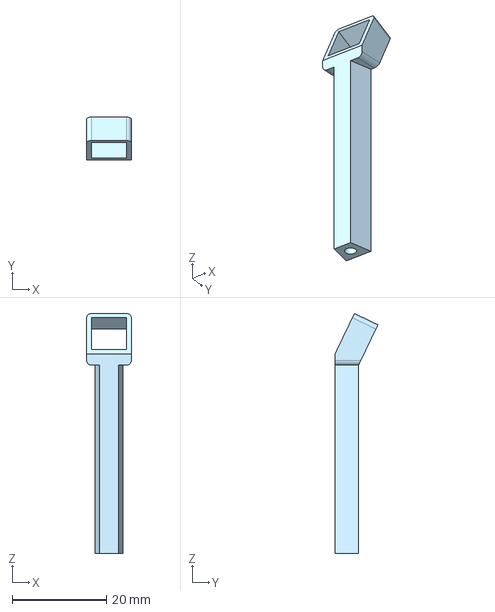
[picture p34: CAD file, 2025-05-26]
CAD/New head with larger base plate/cam_stand/Cam stand 4-22.5.step
9.50 x 9.11 x 51.0 mm

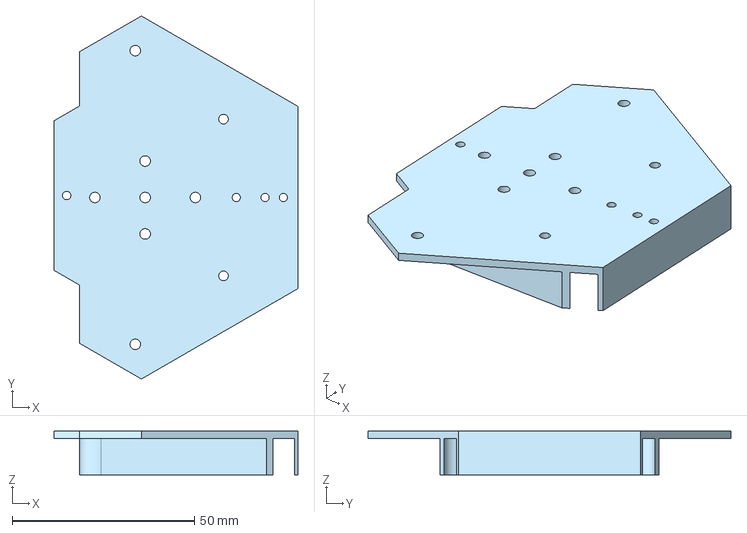
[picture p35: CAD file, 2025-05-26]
CAD/New head with larger base plate/second floor 5.0.step
66.9 x 99.6 x 12.0 mm

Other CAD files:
CAD/Electrical Components/Solidworks Complete Assembly/Rpi components/Raspberry Pi 399.sldprt
CAD/Internal Mechanics/3D parts/Wobbly wobb.step
CAD/Moving Parts/3D parts/Tri Link.step
CAD/New head with larger base plate/cam_stand/Cam stand 5-22.5.step
CAD/Electrical Components/Solidworks Complete Assembly/Rpi components/HANRUN2_HR911105A.sldprt
CAD/Electrical Components/Solidworks Complete Assembly/Rpi components/MOLEX_1040310811.sldprt
CAD/Electrical Components/Solidworks Complete Assembly/Rpi components/MOLEX_672983090.sldprt
CAD/Electrical Components/Solidworks Complete Assembly/Rpi components/PJ-322.sldprt
CAD/Electrical Components/Solidworks Complete Assembly/Rpi components/Raspberry Pi 31.sldprt
CAD/Electrical Components/Solidworks Complete Assembly/Rpi components/Raspberry Pi 310.sldprt
CAD/Electrical Components/Solidworks Complete Assembly/Rpi components/Raspberry Pi 3100.sldprt
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

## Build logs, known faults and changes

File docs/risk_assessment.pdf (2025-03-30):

# Risk Assessment Document

### HexaPolo

### March 30, 2025

## Introduction

This document outlines the risks to the success of our hexabot. It identifies technological challenges and risks that may cause the project to fail, as well as strategies to address these risks early in the project timeline.

## Identified Risks and Mitigation Strategies

### 1. Communication Between Multiple Microcontrollers/Computers

Risk: Ensuring robust communication between multiple microcontrollers or computers using mechanisms such as WiFi, serial communication, or a combination of methods. Challenges include insufficient pins for communication and signal exchange with sensors and motor drivers. Another risk could be the speaker not working. In this case we wouldn’t hear it saying ”Marco” and we would have a hard time answering ”Polo”. Mitigation:

- Conduct a feasibility study to determine the best communication protocol.
- Build a prototype to test communication between micro-controllers under realistic conditions.
- Verify that micro-controllers have sufficient pins for all intended connections.

### 2. Power Supply and Voltage Management

Risk: Supplying multiple different voltages to various components (e.g., motors, microcontrollers) and ensuring smooth operation. The battery we are using (LiPo 7.4 2S) might not provide enough power for the tow 6VN20 motors. Furthermore, since we are connecting the ESP32-CAM to the Pi through ESP32 → FTDI –(USB)→ Pi, there is a risk that it won’t get enough power. Mitigation:

- As a backup for the esp32-cam, we could wire it directly or make it communicate wirelessly with the pi.
- Add a separate battery to help the initial one power the motors.
- Create a prototype including all power consumers and power supplies/converters.
- Test motors under approximate mechanical loads to ensure smooth operation.

1

### 3. Actuator Strength and Mechanical Advantage

Risk: Actuators may not be strong enough for their intended purpose, especially when working against the hexabot’s weight or overcoming substantial inertia in longer kinematic chains. Indeed, the entire weight of our robot being supported by only two motors might restrict its movements. Mitigation:

- Make the 3d print as light as possible by having the filling lower than 30%
- Evaluate actuator strength through prototype testing.
- Experiment with gearboxes, belt reductions, or other mechanical advantages.

### 4. Team Weaknesses and Knowledge Gaps

Risk: Lack of expertise in certain aspects of the project may lead to overly optimistic assumptions or wishful thinking. This might occur in our software ambitions as it is hard to evaluate how many tools and resources already exist online. f there is a lack of them, we might face difficulties implementing substantial software features. Mitigation:

- Identify knowledge gaps and assign team members to research and address them.
- Schedule regular team reviews to critically assess progress and assumptions.
- Seek advice from mentors or experts in areas where the team lacks experience.

## Planned Prototypes

The following prototypes will be developed to address the identified risks:

1. Communication prototype to test micro-controller interactions.
2. Power supply prototype to validate voltage management and motor operation.
3. Actuator prototype to evaluate strength and mechanical advantage.

## Conclusion

By addressing these risks early in the project timeline, we aim to mitigate potential challenges and increase the likelihood of project success. Dependencies and planned prototypes have been incorporated into the project task breakdown.

2

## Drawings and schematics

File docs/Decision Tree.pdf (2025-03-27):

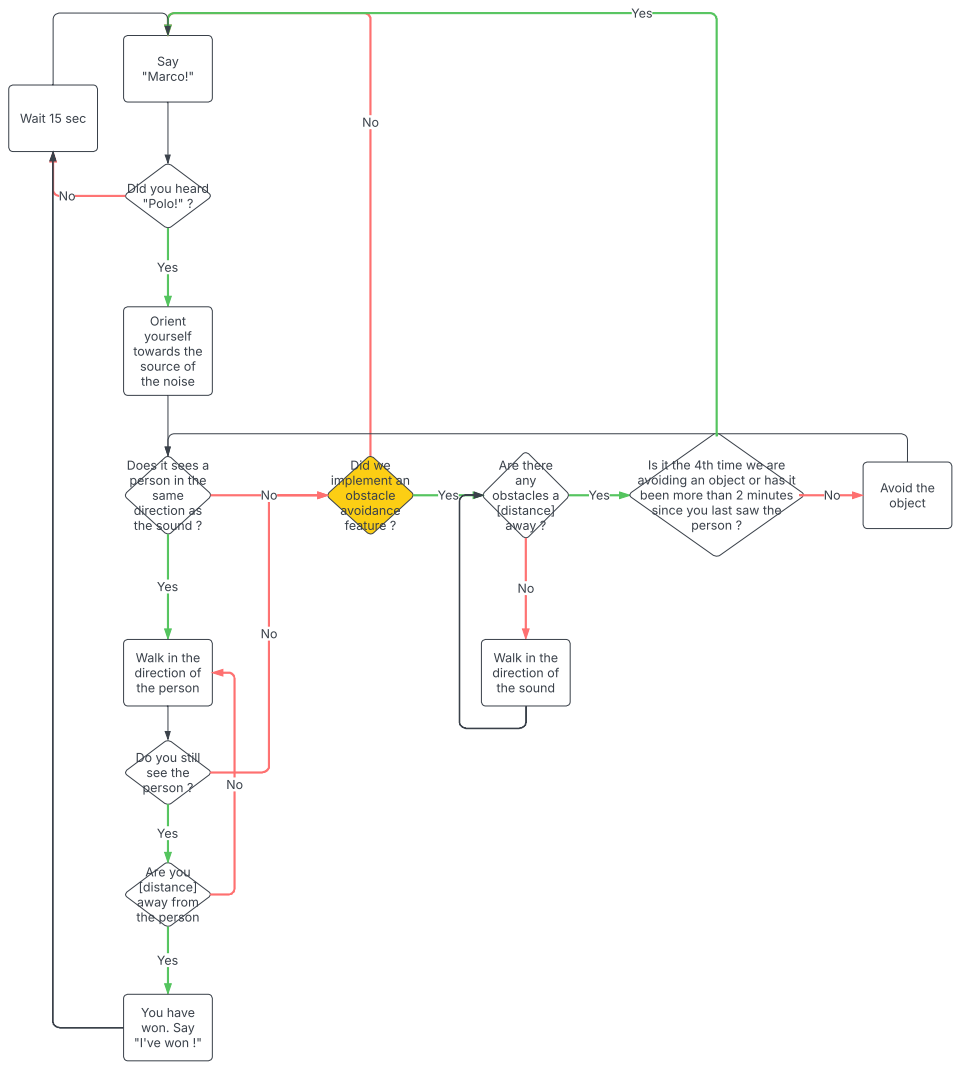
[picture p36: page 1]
Say "Marco!"; Yes; Orient yourself towards the source of the noise; Are there any obstacles a [distance] away ?; Are you [distance] away from the person; Avoid the object; Did we implement an obstacle avoidance feature ?; You have won. Say "I've won !"; Wait 15 sec

Did you heard
"Polo!" ?

Does it sees a
person in the
same
direction as
the sound ?

Is it the 4th time we are
avoiding an object or has it
been more than 2 minutes
since you last saw the
person ?

Walk in the
direction of
the person

the sound

Do you still
see the

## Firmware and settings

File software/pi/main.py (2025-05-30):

from time import sleep
import logging
import signal
import subprocess
import sys
from audio import get_doa_angle
from play_wav import play_wav
from basic_movement import forward, turn
from read_from_serial import SerialReader
from calibrate_and_detect import calibrate

# Global flag for graceful shutdown
shutdown_flag = False
continue_follow = False

def setup_logging():
    """Setup logging configuration for service operation"""
    logging.basicConfig(
        level=logging.INFO,
        format='%(asctime)s - %(name)s - %(levelname)s - %(message)s',
        handlers=[
            logging.FileHandler('/var/log/robot_control.log'),
            logging.StreamHandler(sys.stdout)
        ]
    )
    return logging.getLogger(__name__)

def signal_handler(signum, frame):
    """Handle shutdown signals gracefully"""
    global shutdown_flag, continue_follow
    logger = logging.getLogger(__name__)
    logger.info(f"Received signal {signum}, initiating graceful shutdown...")
    shutdown_flag = True
    continue_follow = False

# Setup signal handlers
signal.signal(signal.SIGTERM, signal_handler)
signal.signal(signal.SIGINT, signal_handler)

def handle_command(command):
    """Handle incoming commands from ESP32"""
    global continue_follow
    logger = logging.getLogger(__name__)

    try:
        cmd = command.split()
        if len(cmd) >= 1:
            direction = cmd[0].lower()
            if direction == "stop":
                logger.info("Received STOP command, stopping follow mode")
                continue_follow = False 
            else:
                angle = float(cmd[1])  # Convert angle to float
                if direction == 'left':
                    angle *= -1
                logger.info(f"Executing turn command: {direction} {angle}°")
                turn(angle)
        else:
            logger.warning(f"Invalid command format: {command}")
    except Exception as e:
        logger.error(f"Error processing command '{command}': {e}")

def follow():
    global continue_follow, shutdown_flag
    logger = logging.getLogger(__name__)
    
    logger.info("Starting follow mode - initializing serial communication")
    serial_reader = SerialReader(port='/dev/ttyUSB0', callback=handle_command)
    serial_reader.start()
    continue_follow = True
    serial_reader.send_message("start")

    try:
        logger.info("Follow mode active - robot will move forward and respond to turn commands")
        while continue_follow and not shutdown_flag:
            forward(0.5)
            sleep(0.1)  # Small delay to check flags more frequently
    except KeyboardInterrupt:
        logger.info("Follow mode interrupted by user")
    except Exception as e:
        logger.error(f"Error in follow mode: {e}")
    finally:
        logger.info("Stopping follow mode and closing serial connection")
        serial_reader.send_message("stop")
        serial_reader.stop()

def main_control_loop(threshold):
    logger = logging.getLogger(__name__)
    
    logger.info("Starting main robot control loop")
    logger.info("Robot will listen for audio DOA, turn toward sound, then follow movement commands")

    try:
        while not shutdown_flag:
            try:
                play_wav(path="/home/hexapolo/project/Marco.wav")
                doa = get_doa_angle(threshold)
                if not doa:
                    logger.info("DOA loop interrupted, stopping main loop")
                    break
                elif doa is not None:
                    logger.info(f"DOA detected at {doa}°, turning toward sound source")
                    turn(doa)
                    sleep(0.5)
                    logger.info("Entering follow mode")
                    follow()
                    if shutdown_flag:
                        break
                else:
                    # No DOA detected, wait a bit before trying again
                    sleep(2)
            except Exception as e:
                logger.error(f"Error in main control loop iteration: {e}")
                sleep(1)  # Wait before retrying
                
    except KeyboardInterrupt:
        logger.info("Main control loop interrupted by user")
    except Exception as e:
        logger.error(f"Fatal error in main control loop: {e}")
    finally:
        logger.info("Main control loop terminated")

if __name__ == "__main__":
    logger = setup_logging()
    logger.info("Robot Control Service Starting...")
    logger.info("System: ESP32 Camera -> Laptop CV -> ESP32 -> Pi Robot Control")

    try:
        threshold = calibrate()
        main_control_loop(threshold)
    except Exception as e:
        logger.error(f"Fatal error in robot control service: {e}")
        sys.exit(1)
    finally:
        logger.info("Robot Control Service Stopped")

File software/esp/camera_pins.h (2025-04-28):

#if defined(CAMERA_MODEL_WROVER_KIT)
#define PWDN_GPIO_NUM -1
#define RESET_GPIO_NUM -1
#define XCLK_GPIO_NUM 21
#define SIOD_GPIO_NUM 26
#define SIOC_GPIO_NUM 27

#define Y9_GPIO_NUM 35
#define Y8_GPIO_NUM 34
#define Y7_GPIO_NUM 39
#define Y6_GPIO_NUM 36
#define Y5_GPIO_NUM 19
#define Y4_GPIO_NUM 18
#define Y3_GPIO_NUM 5
#define Y2_GPIO_NUM 4
#define VSYNC_GPIO_NUM 25
#define HREF_GPIO_NUM 23
#define PCLK_GPIO_NUM 22

#elif defined(CAMERA_MODEL_ESP_EYE)
#define PWDN_GPIO_NUM -1
#define RESET_GPIO_NUM -1
#define XCLK_GPIO_NUM 4
#define SIOD_GPIO_NUM 18
#define SIOC_GPIO_NUM 23

#define Y9_GPIO_NUM 36
#define Y8_GPIO_NUM 37
#define Y7_GPIO_NUM 38
#define Y6_GPIO_NUM 39
#define Y5_GPIO_NUM 35
#define Y4_GPIO_NUM 14
#define Y3_GPIO_NUM 13
#define Y2_GPIO_NUM 34
#define VSYNC_GPIO_NUM 5
#define HREF_GPIO_NUM 27
#define PCLK_GPIO_NUM 25

#define LED_GPIO_NUM 22

#elif defined(CAMERA_MODEL_M5STACK_PSRAM)
#define PWDN_GPIO_NUM -1
#define RESET_GPIO_NUM 15
#define XCLK_GPIO_NUM 27
#define SIOD_GPIO_NUM 25
#define SIOC_GPIO_NUM 23

#define Y9_GPIO_NUM 19
#define Y8_GPIO_NUM 36
#define Y7_GPIO_NUM 18
#define Y6_GPIO_NUM 39
#define Y5_GPIO_NUM 5
#define Y4_GPIO_NUM 34
#define Y3_GPIO_NUM 35
#define Y2_GPIO_NUM 32
#define VSYNC_GPIO_NUM 22
#define HREF_GPIO_NUM 26
#define PCLK_GPIO_NUM 21

#elif defined(CAMERA_MODEL_M5STACK_V2_PSRAM)
#define PWDN_GPIO_NUM -1
#define RESET_GPIO_NUM 15
#define XCLK_GPIO_NUM 27
#define SIOD_GPIO_NUM 22
#define SIOC_GPIO_NUM 23

#define Y9_GPIO_NUM 19
#define Y8_GPIO_NUM 36
#define Y7_GPIO_NUM 18
#define Y6_GPIO_NUM 39
#define Y5_GPIO_NUM 5
#define Y4_GPIO_NUM 34
#define Y3_GPIO_NUM 35
#define Y2_GPIO_NUM 32
#define VSYNC_GPIO_NUM 25
#define HREF_GPIO_NUM 26
#define PCLK_GPIO_NUM 21

#elif defined(CAMERA_MODEL_M5STACK_WIDE)
#define PWDN_GPIO_NUM -1
#define RESET_GPIO_NUM 15
#define XCLK_GPIO_NUM 27
#define SIOD_GPIO_NUM 22
#define SIOC_GPIO_NUM 23

#define Y9_GPIO_NUM 19
#define Y8_GPIO_NUM 36
#define Y7_GPIO_NUM 18
#define Y6_GPIO_NUM 39
#define Y5_GPIO_NUM 5
#define Y4_GPIO_NUM 34
#define Y3_GPIO_NUM 35
#define Y2_GPIO_NUM 32
#define VSYNC_GPIO_NUM 25
#define HREF_GPIO_NUM 26
#define PCLK_GPIO_NUM 21

#define LED_GPIO_NUM 2

#elif defined(CAMERA_MODEL_M5STACK_ESP32CAM)
#define PWDN_GPIO_NUM -1
#define RESET_GPIO_NUM 15
#define XCLK_GPIO_NUM 27
#define SIOD_GPIO_NUM 25
#define SIOC_GPIO_NUM 23

#define Y9_GPIO_NUM 19
#define Y8_GPIO_NUM 36
#define Y7_GPIO_NUM 18
#define Y6_GPIO_NUM 39
#define Y5_GPIO_NUM 5
#define Y4_GPIO_NUM 34
#define Y3_GPIO_NUM 35
#define Y2_GPIO_NUM 17
#define VSYNC_GPIO_NUM 22
#define HREF_GPIO_NUM 26
#define PCLK_GPIO_NUM 21

#elif defined(CAMERA_MODEL_M5STACK_UNITCAM)
#define PWDN_GPIO_NUM -1
#define RESET_GPIO_NUM 15
#define XCLK_GPIO_NUM 27
#define SIOD_GPIO_NUM 25
#define SIOC_GPIO_NUM 23

#define Y9_GPIO_NUM 19
#define Y8_GPIO_NUM 36
#define Y7_GPIO_NUM 18
#define Y6_GPIO_NUM 39
#define Y5_GPIO_NUM 5
#define Y4_GPIO_NUM 34
#define Y3_GPIO_NUM 35
#define Y2_GPIO_NUM 32
#define VSYNC_GPIO_NUM 22
#define HREF_GPIO_NUM 26
#define PCLK_GPIO_NUM 21

#elif defined(CAMERA_MODEL_M5STACK_CAMS3_UNIT)
#define PWDN_GPIO_NUM -1
#define RESET_GPIO_NUM 21
#define XCLK_GPIO_NUM 11
#define SIOD_GPIO_NUM 17
#define SIOC_GPIO_NUM 41

#define Y9_GPIO_NUM 13
#define Y8_GPIO_NUM 4
#define Y7_GPIO_NUM 10
#define Y6_GPIO_NUM 5
#define Y5_GPIO_NUM 7
#define Y4_GPIO_NUM 16
#define Y3_GPIO_NUM 15
#define Y2_GPIO_NUM 6
#define VSYNC_GPIO_NUM 42
#define HREF_GPIO_NUM 18
#define PCLK_GPIO_NUM 12

#define LED_GPIO_NUM 14

#elif defined(CAMERA_MODEL_AI_THINKER)
#define PWDN_GPIO_NUM 32
#define RESET_GPIO_NUM -1
#define XCLK_GPIO_NUM 0
#define SIOD_GPIO_NUM 26
#define SIOC_GPIO_NUM 27

#define Y9_GPIO_NUM 35
#define Y8_GPIO_NUM 34
#define Y7_GPIO_NUM 39
#define Y6_GPIO_NUM 36
#define Y5_GPIO_NUM 21
#define Y4_GPIO_NUM 19
#define Y3_GPIO_NUM 18
#define Y2_GPIO_NUM 5
#define VSYNC_GPIO_NUM 25
#define HREF_GPIO_NUM 23
#define PCLK_GPIO_NUM 22

// 4 for flash led or 33 for normal led
#define LED_GPIO_NUM 4

#elif defined(CAMERA_MODEL_TTGO_T_JOURNAL)
#define PWDN_GPIO_NUM 0
#define RESET_GPIO_NUM 15
#define XCLK_GPIO_NUM 27
#define SIOD_GPIO_NUM 25
#define SIOC_GPIO_NUM 23

#define Y9_GPIO_NUM 19
#define Y8_GPIO_NUM 36
#define Y7_GPIO_NUM 18
#define Y6_GPIO_NUM 39
#define Y5_GPIO_NUM 5
#define Y4_GPIO_NUM 34
#define Y3_GPIO_NUM 35
#define Y2_GPIO_NUM 17
#define VSYNC_GPIO_NUM 22
#define HREF_GPIO_NUM 26
#define PCLK_GPIO_NUM 21

#elif defined(CAMERA_MODEL_XIAO_ESP32S3)
#define PWDN_GPIO_NUM -1
#define RESET_GPIO_NUM -1
#define XCLK_GPIO_NUM 10
#define SIOD_GPIO_NUM 40
#define SIOC_GPIO_NUM 39

#define Y9_GPIO_NUM 48
#define Y8_GPIO_NUM 11
#define Y7_GPIO_NUM 12
#define Y6_GPIO_NUM 14
#define Y5_GPIO_NUM 16
#define Y4_GPIO_NUM 18
#define Y3_GPIO_NUM 17
#define Y2_GPIO_NUM 15
#define VSYNC_GPIO_NUM 38
#define HREF_GPIO_NUM 47
#define PCLK_GPIO_NUM 13
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

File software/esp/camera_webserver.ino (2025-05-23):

#include "esp_camera.h"
#include <HTTPClient.h> // HTTP client functionality
#include <WebServer.h>
#include <WiFi.h>
#include <cstdlib>

//
// WARNING!!! PSRAM IC required for UXGA resolution and high JPEG quality
//            Ensure ESP32 Wrover Module or other board with PSRAM is selected
//            Partial images will be transmitted if image exceeds buffer size
//
//            You must select partition scheme from the board menu that has at
//            least 3MB APP space. Face Recognition is DISABLED for ESP32 and
//            ESP32-S2, because it takes up from 15 seconds to process single
//            frame. Face Detection is ENABLED if PSRAM is enabled as well

// ===================
// Select camera model
// ===================
#define CAMERA_MODEL_AI_THINKER // Has PSRAM
#include "camera_pins.h"
// Store wifi password in separate file to not expose it when pushing to git
#include "wifi_password.h"

// #define WIFI_SSID ENV_WIFI_SSID
// #define WIFI_PASSWORD ENV_WIFI_PASSWORD
//  ===========================
//  Enter your WiFi credentials
//  ===========================
// Check issue #32 comment on using IOT WiFi
const char *ssid = "SPOT-iot";
const char *password = WIFI_PASSWORD;

// Web Server on port 80 (for messaging)
WebServer server(8080);

String lastReceivedMessage = ""; // Store the last received message from the Pi

const char *LAPTOP_IP = "172.21.68.88"; // Replace with your laptop's IP
const int LAPTOP_PORT = 5000;
String LAPTOP_ENDPOINT = "http://" + String(LAPTOP_IP) + ":" +
                         String(LAPTOP_PORT) + "/esp32_message";

void sendToLaptop(String message) {
  WiFiClient client;
  HTTPClient http;

  http.begin(client, LAPTOP_ENDPOINT);
  http.addHeader("Content-Type", "application/json");

  String payload = "{\"text\":\"" + message + "\"}";
  int httpResponseCode = http.POST(payload);

  if (httpResponseCode <= 0) {
    Serial.println("Error sending to laptop: " + String(httpResponseCode));
  }

  http.end();
}

// ===================
// Camera Setup (unchanged)
// ===================
void startCameraServer();
void setupLedFlash(int pin);

void setup() {
  Serial.begin(115200);
  Serial.setDebugOutput(true);
  Serial.println();

  camera_config_t config;
  config.ledc_channel = LEDC_CHANNEL_0;
  config.ledc_timer = LEDC_TIMER_0;
  config.pin_d0 = Y2_GPIO_NUM;
  config.pin_d1 = Y3_GPIO_NUM;
  config.pin_d2 = Y4_GPIO_NUM;
  config.pin_d3 = Y5_GPIO_NUM;
  config.pin_d4 = Y6_GPIO_NUM;
  config.pin_d5 = Y7_GPIO_NUM;
  config.pin_d6 = Y8_GPIO_NUM;
  config.pin_d7 = Y9_GPIO_NUM;
  config.pin_xclk = XCLK_GPIO_NUM;
  config.pin_pclk = PCLK_GPIO_NUM;
  config.pin_vsync = VSYNC_GPIO_NUM;
  config.pin_href = HREF_GPIO_NUM;
  config.pin_sccb_sda = SIOD_GPIO_NUM;
  config.pin_sccb_scl = SIOC_GPIO_NUM;
  config.pin_pwdn = PWDN_GPIO_NUM;
  config.pin_reset = RESET_GPIO_NUM;
  config.xclk_freq_hz = 20000000;
  config.frame_size = FRAMESIZE_VGA;
  config.pixel_format = PIXFORMAT_JPEG; // for streaming
  // config.pixel_format = PIXFORMAT_RGB565; // for face detection/recognition
  config.grab_mode = CAMERA_GRAB_WHEN_EMPTY;
  config.fb_location = CAMERA_FB_IN_PSRAM;
  config.jpeg_quality = 12;
  config.fb_count = 1;

  // if PSRAM IC present, init with UXGA resolution and higher JPEG quality
  // for larger pre-allocated frame buffer.
  if (config.pixel_format == PIXFORMAT_JPEG) {
    if (psramFound()) {
      config.jpeg_quality = 10;
      config.fb_count = 2;
      config.grab_mode = CAMERA_GRAB_LATEST;
    } else {
      // Limit the frame size when PSRAM is not available
      config.frame_size = FRAMESIZE_QVGA;
      config.fb_location = CAMERA_FB_IN_DRAM;
    }
  } else {
    // Best option for face detection/recognition
    config.frame_size = FRAMESIZE_240X240;
#if CONFIG_IDF_TARGET_ESP32S3
    config.fb_count = 2;
#endif
  }

  // camera init
  esp_err_t err = esp_camera_init(&config);
  if (err != ESP_OK) {
    Serial.printf("Camera init failed with error 0x%x", err);
    return;
  }

  sensor_t *s = esp_camera_sensor_get();
  // drop down frame size for higher initial frame rate
  if (config.pixel_format == PIXFORMAT_JPEG) {
    s->set_framesize(s, FRAMESIZE_QVGA);
  }

// Setup LED FLash if LED pin is defined in camera_pins.h
#if defined(LED_GPIO_NUM)
  setupLedFlash(LED_GPIO_NUM);
#endif

  WiFi.begin(ssid, password);
  WiFi.setSleep(false);

  Serial.print("WiFi connecting");
  while (WiFi.status() != WL_CONNECTED) {
    delay(500);
    Serial.print(".");
  }
  Serial.println("");
  Serial.println("WiFi connected");

  startCameraServer();

  Serial.print("Camera Ready! Use 'http://");
  Serial.print(WiFi.localIP());
  Serial.println("' to connect");

  // Setup HTTP server for messaging (new)
  server.on("/message", HTTP_GET, []() {
    if (server.hasArg("text")) {
      String message = server.arg("text");
      Serial.println(message); // Send to Raspberry Pi via Serial
      server.send(200, "text/plain", "OK");
    } else {
      server.send(400, "text/plain", "ERROR: Missing 'text' parameter");
    }
  });

  server.begin();
  Serial.println("HTTP messaging server started");
}

void loop() {
  server.handleClient();

  if (Serial.available() > 0) {
    String message = Serial.readStringUntil('\n');
    message.trim();

    if (message != "") {
      lastReceivedMessage = message;

      // Send this message to the laptop
      sendToLaptop(lastReceivedMessage);
    }
  }
}

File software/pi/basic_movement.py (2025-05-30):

from gpiozero import Motor
from time import sleep
import logging

# Setup logger
logger = logging.getLogger(__name__)

walk_motor = Motor(forward=4, backward=11)
turn_motor = Motor(forward=23, backward=24)

def forward(duration=1, speed=1):
    """Move forward for specified duration in seconds"""
    logger.info(f"Walking forward for {duration} second(s) at speed {speed}")
    try:
        walk_motor.forward(speed)
        sleep(duration)
        walk_motor.stop()
        logger.debug(f"Forward movement completed successfully")
    except Exception as e:
        logger.error(f"Error during forward movement: {e}")
        walk_motor.stop()  # Ensure motor stops on error
        raise

def turn(angle, speed=1):
    """Turn by specified angle in degrees (positive=right, negative=left)"""
    # Convert angle to time-based turn (simplified approach)
    # Shortest turn
    if angle > 180:
        angle -= 360
    elif angle < -180:
        angle += 360
    
    direction = 'CCW' if angle > 0 else 'CW'
    logger.info(f"Turning {direction} by {abs(angle)}° at speed {speed}")

    turn_time = abs(angle) / 50 * 0.5  # 0.5s per 90 degrees
    logger.debug(f"Calculated turn time: {turn_time:.2f} seconds")

    try:
        if angle > 0:
            turn_motor.backward(speed)
        else:
            turn_motor.forward(speed)

        sleep(turn_time)
        turn_motor.stop()
        logger.debug(f"Turn movement completed successfully")
    except Exception as e:
        logger.error(f"Error during turn movement: {e}")
        turn_motor.stop()  # Ensure motor stops on error
        raise

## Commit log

2025-03-28 Internal mechanics CADs
    [Big rotary gear.step, Combined internal mechanics.step, Drive pinion.step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]
2025-03-29 Small update
    [Combined internal mechanics.step, Upper collar.step]
2025-03-30 Add 3D files for legs related components
    [All legs components.step, Control link.step, Leg.step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]
2025-03-30 Add CAD for electronic plate to hold electronics
    [Electronic plate.step]
2025-03-30 Add Hexapod global 3D structure image and step file
    [Hexapod global 3D structure.step]
2025-04-13 leg is re-designed to be lighter and grip more on surfaces
    [hexapolo leg re-designed.step]
2025-04-13 Update STEP files for the most up-to-date designs
    [Big rotary gear.step, Control link.step, Gear box.step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]
2025-04-13 head of hexabot done
    [Drive_Cage.step, Head_Base.step, Head_Bracket.step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]
2025-04-14 fillets added
    [hexapolo leg re-designed.step]
2025-04-15 head mount's base plate width was thicken to ensure a stronger structural integrity
    [Head_Mount.step]
2025-04-15 streaming from esp32-cam works
2025-05-02 implement YOLO-based human movement detection with ESP32-CAM streaming
2025-05-07 Head done, CAD model of a few electrical components were added and the MIT_proposal was add to the repo
    [FTDI UART FT232 USB board v7.step, First Floor.step, Fourth Floor.step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]
2025-05-12 head was redesigned to its final version
    [First Floor.step, Fourth Floor.step, Gear box (Revised).step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]
2025-05-15 new design for head
    [Gear box 2.0.step, column.step, first floor 3.0 without columns.step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]
2025-05-19 reorganised code
    [odas.cfg]
2025-05-20 calibrated audio sensor and turning
2025-05-20 Add initial scripts for ESP32-CAM communication and message handling
2025-05-21 Implement Flask server for ESP32-CAM message handling and improve message input prompts
2025-05-21 ESP32 code: send/receive via serial and Wifi
2025-05-21 Pi's code: receive serial messages from ESP32
2025-05-21 A test-try file to test communication between Laptop and ESP32 via wifi
2025-05-21 Update: now sending information via wifi to ESP32 which forwards to Pi
2025-05-23 Revert "organization-rename"
    This reverts commit 2cd8a34f3dda9461d4e1ea8d37f9c2c978677c97.
    [read_from_serial.py]
2025-05-23 Revert "organization-rename"
    This reverts commit a15e3744c8c121914b45aac33eda3ec62f21b74f.
    [read_from_serial.py]
2025-05-25 cam slot addad
    [first floor 4.0 without columns.step]
2025-05-25 new organisation
    [odas.cfg]
2025-05-25 fixed motor movement
2025-05-26 the first floor of the head can now accomodate three different angles for the camera placement
    [first floor 5.0 without columns Copy 1.step, higher_column.step]
2025-05-26 CAD files added
    [BMS protection board case.step, Cam stand 4-22.5.step, Cam stand 4-45.step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]
2025-05-27 python scripts to calibrate recognition in a load room and script to recognize the sound
2025-05-27 script to adapte the background noise filtering and then detecting a single frequency sound
    [calibrate_and_detect.py]
